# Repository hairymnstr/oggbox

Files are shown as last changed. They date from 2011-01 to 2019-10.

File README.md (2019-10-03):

OggBox
======

Author: nathan@nathandumont.com
License: 
* C code directly contained in this repository BSD-2-clause
* 3rd party libraries (FreeRTOS etc) see their own license terms
* schematic and CAD files CC0 1.0

The OggBox is an open hardware music player.  It supports OggVorbis and WAV files
using a dedicated codec chip from VLSI.  The source code for the main processor
(an ARM Cortex) is written in C and can be found under src/firmware.

Originally it was developed using the toolchain built with
<https://github.com/esden/summon-arm-toolchain> but can be built with newer
toolchains that provide arm-none-eabi-gcc and an appropriate newlib

    sudo apt install gcc-arm-none-eabi

will install a suitable toolchain on Ubuntu 18.04.

Flashing the device can be done via a suitable SWD probe and OpenOCD, or using
the FTDI header and <https://sourceforge.net/p/stm32flash/wiki/Home/>.  You may 
need to adjust the Makefile as the install target uses a specific device on my
computer so that it doesn't try and access any other FTDI devices attached to my PC.

The schematics have recently been ported to KiCAD v5.2 format and are under /sch
the libraries required are pulled in as local to the project as git submodules.

What documentation exists is linked from <http://oggbox.nathandumont.com>

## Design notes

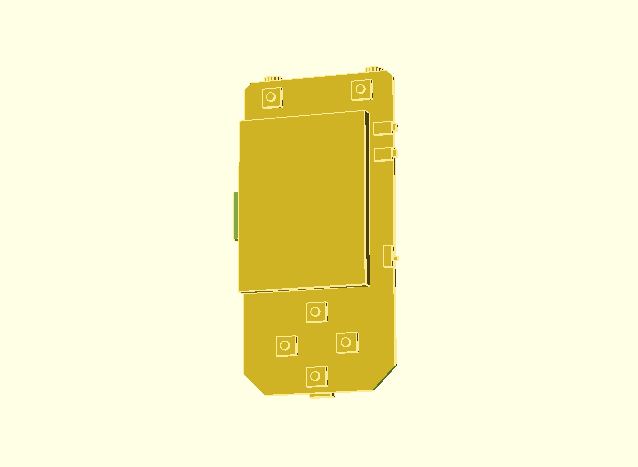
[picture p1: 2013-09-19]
cad/pcba_front.png

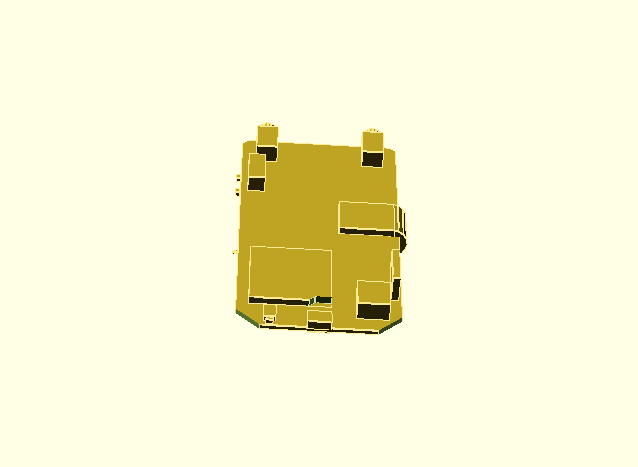
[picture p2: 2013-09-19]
cad/pcba_back.png

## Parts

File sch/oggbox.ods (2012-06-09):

Reference | Value | Footprint | Qty. | Farnell | Stock
B1 | LIPO | JUMPER | 1 |  | 1
C1, C2 | 18p | SM0805 | 2 | 1759194
C19, C22, C26, C30, C47, C48 | 4.7u | SM0805 | 6 | 1759420 | 90
C23 | 47u | SM1206 | 1 | 1658446
C24, C25 | 10p | SM0805 | 2 | 1759191
C28, C29 | 27p | SM0805 | 2 | 1759196
C3, C4, C43, C44 | 1u | SM0805 | 4 | 1759422
C37, C39, C40, C41 | 2.2u | SM0805 | 4 | 1759177 | 96
C5, C6, C18, C20, C21 | 0.01u | SM0805 | 5 | 1759247
C7, C8, C9, C10, C11, C12, C13, C14, C15, C16, C17, C27, C32, C33, C34, C35, C36, C42, C45, C46, C49, C50, C51, C52, C53, C54, C55 | 0.1u | SM0805 | 27 | 1759166 | 95
D1 | LED_RG | SOT23 | 1 | 1142614
IC1 | VS1053 | LQFP48 | 1 | --- | 1
IC2 | MCP73831T | SOT23-5 | 1 | 1332158 | 2
IC3 | SD_CARD | SD_CARD9186158 | 1 | 9186158
IC4 | MCP1802T-3002I-OT | SOT23-5 | 1 | 1578373
IC5 | STM32F103RBT | LQFP64 | 1 | 1447640
IC7 | TPS76318 | SOT23-5 | 1 | 8461341
IC8 | TPS76328 | SOT23-5 | 1 | 1755503
IC9 | MCP102 | SOT23 | 1 | 8752842
L1 | 470n | SM1206 | 1 | 1711870
P2 | USB | MICRO_USB_1568026 | 1 | 1568026
P5 | CONN_4 | BTHQ128064AVD1 | 1 | 9449388
P6 | CONN_28 | AMP_FPC_28_05MM | 1 | 1816385
P7 | FTDI | HEADER_6 | 1 |  | 1
P8 | JTAG | header_smd | 1 |  | 1
P9, P10 | LINE, PHONES | JACK_LUMBERG_1503_13_VP3 | 2 | 1368640
Q1, Q2 | BC817 | SOT23 | 2 | 1081223
Q3, Q4 | BSH121 | SOT23 | 2 | 1758072
R1, R4, R5, R6, R7, R8, R9, R10, R14, R23, R24, R25, R26, R32, R33, R34, R37, R38, R40, R41, R43, R44, R46, R48, R49, R50, R51, R52 | 10k | SM0805 | 28 | 9333720
R12, R42 | 1M | SM0805 | 2 | 9333746 | 49
R13 | 47k | SM0805 | 1 | 9334599
R15 | 36k | SM0805 | 1 | 9334440
R16 | 1.5k | SM0805 | 1 | 9333924
R17, R18 | 470 | SM0805 | 2 | 9334572
R19 | 15k | SM0805 | 1 | 9333932
R2, R11 | 120 | SM0805 | 2 | 9333819
R20, R21 | 22 | SM0805 | 2 | 9334122
R22, R57 | 22k | SM0805 | 2 | 9334157
R27, R28 | 100k | SM0805 | 2 | 9333738
R29 | 10 | SM0805 | 1
R3, R56 | 1k | SM0805 | 2 | 9333711
R30, R31 | 20 | SM0805 | 2
R35 | 3k3 | SM0805 | 1 | 9334360
R36 | 12k | SM0805 | 1 | 9333835
R39 | 0 | SM0805 | 1
R53, R54 | 27 | SM0805 | 2 | 9334246 | 48
SW1, SW2, SW3 | VOL_UP, VOL_DN, RESET | SW_B3U-3000P-B | 3 | 1333656
SW4, SW5, SW7, SW8, SW9, SW10 | MENU, SET, DOWN, LEFT, RIGHT, UP | SW_EVQQ2P03W | 6 | 9962859
SW11 | HOLD | PCM12SMTR | 1 | 9575146
X1 | 12.288MHz | HC49SM | 1 | 1611787
X2 | 32768Hz | CFS206 | 1 | 1457085 | 1
X3 | 8MHz | HC49SM | 1 | 1842346

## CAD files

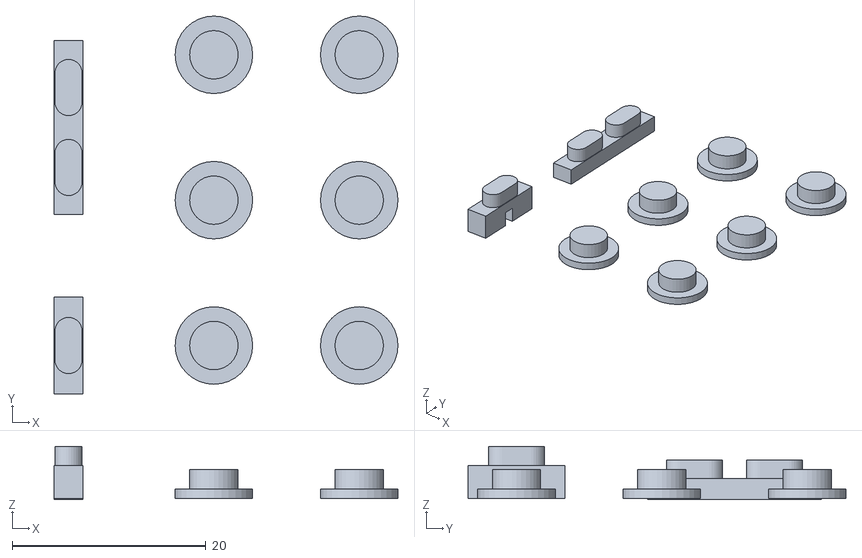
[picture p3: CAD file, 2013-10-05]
cad/oggbox_buttons.stl
35.5 x 39.0 x 5.50

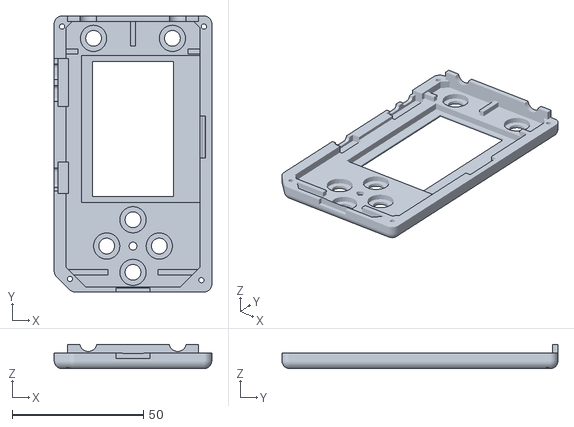
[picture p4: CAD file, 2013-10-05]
cad/oggbox_front.stl
60.0 x 105.0 x 9.24

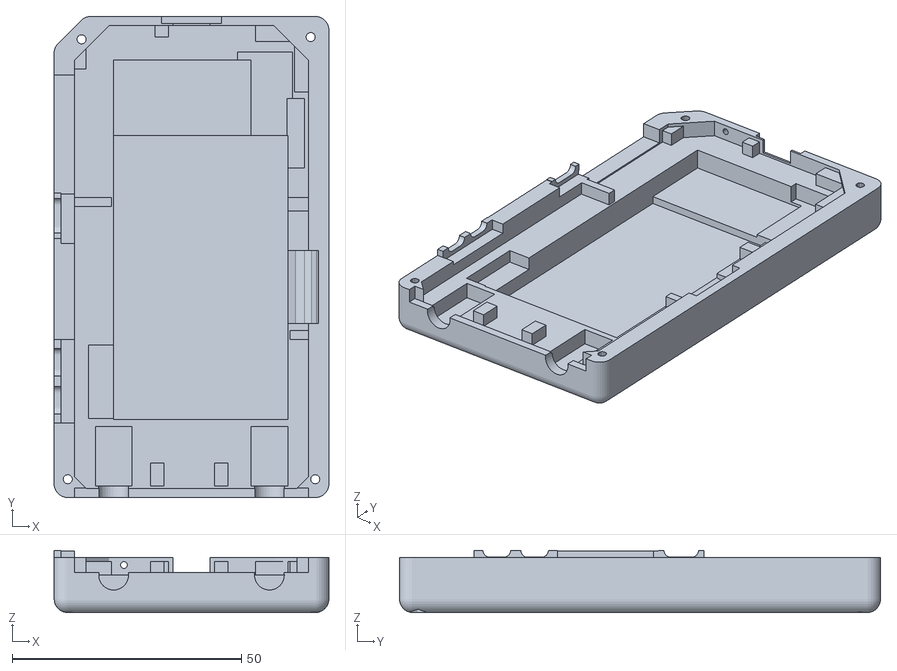
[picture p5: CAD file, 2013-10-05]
cad/oggbox_back.stl
60.0 x 105.0 x 13.6

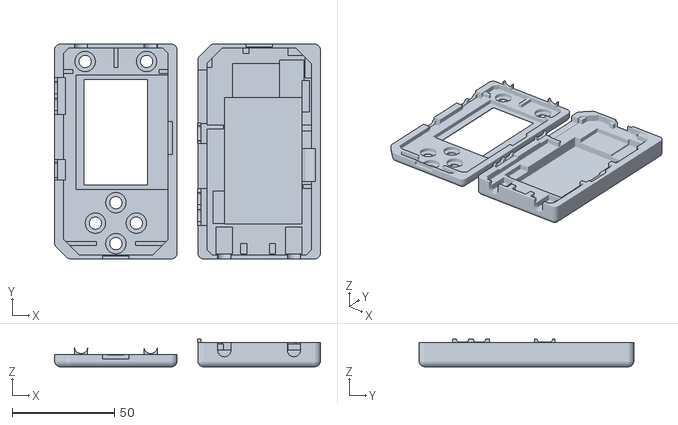
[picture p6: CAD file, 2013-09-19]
cad/oggbox.stl
130.0 x 105.0 x 13.6

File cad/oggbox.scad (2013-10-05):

module screen() {
	union() {
		difference() {
			translate([1.3,1,2.95]) cylinder(r1=5,r2=5,h=14.7,$fn=16, center=true);
			translate([-5,4.405,-5]) cube([10,5,20]);
		}
		translate([-1,0,-27.3]) cube([42.2,4.405,54.6]);
		translate([9.25,-2.75,2.95]) cube([17.5,2.5,14.7], center=true);
	}
}

module switch() {
	union() {
		translate([0,0.9,0]) cube([6.6,1.8,6.2],center=true);
		translate([0,2.3,0]) rotate([90,0,0]) cylinder(r1=1.5, r2=1.5, h=1, $fn=16, center=true);
	}
}

module side_switch() {
	union() {
		translate([0,0.9,0]) cube([4,1.8,6],center=true);
		translate([0,0.9,3.75]) cube([2.4,1.6,1.5],center=true);
	}
}

module hold_switch() {
	union() {
		translate([-3.35,0,-1.4]) cube([6.7,1.95,2.8]);
		translate([-1.5,.575,1.4]) cube([1.35,.8,1.9]);
	}
}

module sdcard_holder() {
	difference() {
		translate([0,0,-13.25]) cube([25,2.5,26.5]);
		translate([-0.1,-0.1,-13.35]) cube([5.1,3,2.1]);
		translate([5,1.25,-13.25]) rotate([0,45,0]) cube([2.828,3,2.828],center=true);
	}
}

module jack_socket() {
	union() {
		translate([-3.5,0,2.5]) cube([7,6,12]);
		translate([0,3,1.5]) rotate() cylinder(r1=3, r2=3, h=2.5, $fn=16, center=true);
	}
}

module usb_socket() {
	translate([-3.75,0,0]) cube([7.5,3,5.5]);
}

module programming_header() {
	translate([-7.62,0,-1.27]) cube([15.24,8.5,2.54]);
}

module cortex_debug() {
	translate([0,2.7,0]) cube([13.65,5.4,5.6], center=true);
}

module battery_connector() {
	translate([-5,0,-9.5]) cube([10,6,11.5]);
}

module pcba() {
	union() {
		// PCB
		difference() {
			cube([50.0,1.6,100.0], center = true);
			translate([25,0,50]) rotate([0,45,0]) cube([3.5355,3.5355,3.5355], center=true);
			translate([-25,0,50]) rotate([0,45,0]) cube([3.5355,3.5355,3.5355], center=true);
			translate([25,0,-50]) rotate([0,45,0]) cube([10.6066,10.6066,10.6066], center=true);
			translate([-25,0,-50]) rotate([0,45,0]) cube([10.6066,10.6066,10.6066], center=true);
		}
		// screen
		translate([24,0.8,9.5]) rotate([0,180,0]) screen();

		// buttons
		translate([15,0.8,44]) switch();
		translate([-15,0.8,44]) switch();
		translate([0,0.8,-25]) switch();
		translate([0,0.8,-45]) switch();
		translate([10,0.8,-35]) switch();
		translate([-10,0.8,-35]) switch();

		// volume switches
		translate([-22,0.8,31.25]) rotate([0,270,0]) side_switch();
		translate([-22,0.8,23]) rotate([0,270,0]) side_switch();
		// reset switch
		translate([-14.75,-0.8,-45]) rotate([0,180,180]) side_switch();

		// hold switch
		translate([-23.5,0.8,-9]) rotate([0,270,0]) hold_switch();

		// sd card holder
		translate([3.75,-0.8,-26.5]) rotate([180,180,0]) sdcard_holder();

		// jack sockets
		translate([-17,-0.8,52.25]) rotate([0,180,180]) jack_socket();
		translate([17,-0.8,52.25]) rotate([0,180,180]) jack_socket();

		// USB socket
		translate([0,-0.8,-51]) rotate([180,180,0]) usb_socket();

		// programming header
		translate([22.75,-0.8,-27]) rotate([180,90,0]) programming_header();

		// Cortex-debug connector
		translate([-20,-0.8,27.25]) rotate([180,90,0]) cortex_debug();

		// battery connector
		translate([16,-0.8,-42.75]) rotate([180,0,0]) battery_connector();

	}
}

module sdcard() {
	difference() {
		cube([24,2.1,32], center=true);
		translate([-12,0,-16]) rotate([0,45,0]) cube([5.65,5.65,5.65], center=true);
	}
}

module button_hole() {
	union() {
		translate([0,4.5,0]) rotate([90,0,0]) cylinder(r1=3,r2=3,h=4,$fn=32,center=true);
		rotate([270,0,0]) cylinder(r1=5,r2=5,h=9.6,$fn=32,center=true);
	}
}

module side_switch_hole() {
	union() {
		translate([2.5,0,0]) cube([4,5,10],center=true);
		cube([3,3,3],center=true);
		translate([0,0,-1.5]) rotate([0,90,0]) cylinder(r1=1.5,r2=1.5,h=3,$fn=32,center=true);
		translate([0,0,1.5]) rotate([0,90,0]) cylinder(r1=1.5,r2=1.5,h=3,$fn=32,center=true);
	}
}

module hold_switch_hole() {
	union() {
		translate([2.5,0,0]) cube([4,5,12],center=true);
		cube([3,3,4.5],center=true);
		translate([0,0,-2.25]) rotate([0,90,0]) cylinder(r1=1.5,r2=1.5,h=3,$fn=32,center=true);
		translate([0,0,2.25]) rotate([0,90,0]) cylinder(r1=1.5,r2=1.5,h=3,$fn=32,center=true);
	}
}

module upper_case() {
	union() {
	difference() {
		union() {
		difference() {
			translate([-27,-3,-49.5]) {
				minkowski() {
					difference() {
						cube([54,6,99]);
						rotate([0,45,0]) cube([sqrt(50),20,sqrt(50)],center=true);
					}
					sphere(r=3,$fn=32);
				}
			}
			translate([0,-3,0]) cube([62,6,106],center=true);
		}
		translate([0,0,51.5]) cube([50,6.5,2],center=true);
		
		}

		// status LED hole
		translate([0,5,-35]) rotate([90,0,0]) cylinder(r1=1.5,r2=1.5,h=5,$fn=32,center=true);

		// button holes
		translate([15,0,44]) button_hole();
		translate([-15,0,44]) button_hole();
		translate([0,0,-25]) button_hole();
		translate([0,0,-45]) button_hole();
		translate([10,0,-35]) button_hole();
		translate([-10,0,-35]) button_hole();

		// volume switch holes
		translate([-29,1.6,31.25]) side_switch_hole();
		translate([-29,1.6,23]) side_switch_hole();

		// hold switch hole
		translate([-29,1.6,-9]) hold_switch_hole();
		translate([-29,0,11.125]) cube([7.1,3,50.25],center=true);
		
		translate([-17,-0.8,52.5]) rotate([0,0,180]) jack_hole();
		translate([17,-0.8,52.5]) rotate([0,0,180]) jack_hole();

		// pcb hole
		difference() {
			cube([51,5.6,101],center=true);
			translate([25.5,0,50.5]) rotate([0,45,0]) cube([3.5355,10,3.5355],center=true);
			translate([-25.5,0,50.5]) rotate([0,45,0]) cube([3.5355,10,3.5355],center=true);
			translate([-25.5,0,-50.5]) rotate([0,45,0]) cube([10.6066,10,10.6066],center=true);
			translate([25.5,0,-50.5]) rotate([0,45,0]) cube([10.6066,10,10.6066],center=true);
		}

		// screen recess
		translate([24,0.8,9.5]) translate([-43.5,-2,-28]) cube([45,6.5,56]);
		
		// screen hole
		translate([-15.5,4,-25.75+9.5]) cube([31,5,51.5]);

		// screen ribbon clearance
		translate([24,0.8,9.5]) translate([-1.3,-1,-2.95]) cylinder(r1=5,r2=5,h=16,$fn=16,center=true);

		// usb socket
		translate([0,0,-51]) usb_socket_hole();

		// screw holes
		translate([26,0,-48]) rotate([90,0,0]) cylinder(r1=1, r2=1, h=30, $fn=16, center=true);
		translate([27,0,48.5]) rotate([90,0,0]) cylinder(r1=1, r2=1, h=30, $fn=16, center=true);
		translate([-27,0,48.5]) rotate([90,0,0]) cylinder(r1=1, r2=1, h=30, $fn=16, center=true);
		translate([-24,0,-47.5]) rotate([90,0,0]) cylinder(r1=1, r2=1, h=30, $fn=16, center=true);
		translate([26,6,-48]) rotate([90,0,0]) cylinder(r1=1.5,r2=1.5,h=3,$fn=32);
		translate([27,6,48.5]) rotate([90,0,0]) cylinder(r1=1.5,r2=1.5,h=3,$fn=32);
		translate([-27,6,48.5]) rotate([90,0,0]) cylinder(r1=1.5,r2=1.5,h=3,$fn=32);
		translate([-24,6,-47.5]) rotate([90,0,0]) cylinder(r1=1.5,r2=1.5,h=3,$fn=32);
	}
	// PCB support bars
	translate([-1,0.8,41]) cube([2,3,10]);
	translate([-24.5,0.8,-46]) cube([15,3,2]);
	translate([9.5,0.8,-46]) cube([15,3,2]);
	translate([21,0.8,38]) cube([5,3,2]);
	translate([-26,0.8,38]) cube([5,3,2]);
	}

}

module jack_hole() {
	union() {
		translate([0,3.25,-9]) cube([8,7,13],center=true);
		translate([0,3,-2.6]) rotate() cylinder(r1=3.25,r2=3.25,h=4,$fn=32);
	}
}

module usb_socket_hole() {
	union() {
		translate([-4,-3.3,-1]) cube([8,3.5,5]);
		translate([-6.5,-5.8,-5]) cube([13,8,5]);
	}
}

module lower_case() {
union() {
	difference() {
	union() {
		translate([-29.25,0.8,31.25]) cube([1.5,1.6,10],center=true);
		translate([-29.25,0.8,23]) cube([1.5,1.6,10],center=true);
		translate([-29.25,0.8,-9]) cube([1.5,1.6,10],center=true);
		translate([-27.75,0,11.125]) cube([4.5,3,50],center=true);
		difference() {
			translate([-27,-9,-49.5]) {
				minkowski() {
					difference() {
						cube([54,12,99]);
						rotate([0,45,0]) cube([sqrt(50),30,sqrt(50)],center=true);
					}
					sphere(r=3,$fn=32);
				}
			}
			translate([0,3,0]) cube([62,6,106],center=true);
		}
		}

		// volume switch holes
		translate([-29,1.6,31.25]) side_switch_hole();
		translate([-29,1.6,23]) side_switch_hole();

		// hold switch hole
		translate([-29,1.6,-9]) hold_switch_hole();

		// pcb hole
		difference() {
			cube([51,7.6,101],center=true);
			translate([25.5,0,50.5]) rotate([0,45,0]) cube([3.5355,10,3.5355],center=true);
			translate([-25.5,0,50.5]) rotate([0,45,0]) cube([3.5355,10,3.5355],center=true);
			translate([-25.5,0,-50.5]) rotate([0,45,0]) cube([10.6066,10,10.6066],center=true);
			translate([25.5,0,-50.5]) rotate([0,45,0]) cube([10.6066,10,10.6066],center=true);
		}

		// screen ribbon clearance
		translate([24,0.8,9.5]) translate([-1.3,-1,-2.95]) cylinder(r1=5,r2=5,h=16,$fn=16,center=true);

		// jack holes
		translate([-17,-0.8,52.5]) rotate([0,0,180]) jack_hole();
		translate([17,-0.8,52.5]) rotate([0,0,180]) jack_hole();
//		translate([-17,0,52.5]) cube([6.5,6.5,6],center=true);
//		translate([17,0,52.5]) cube([6.5,6.5,6],center=true);
		translate([0,0,51.5]) cube([51,6.5,2.1],center=true);
		// cortex debug connector
		translate([-22.5,-6.8,19.25]) cube([7,6,16]);

		// programming header
		translate([22.75-(3.8/2),-9.3,-27 - (15.24/2)]) cube([3.8,8.5,15.24]);
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

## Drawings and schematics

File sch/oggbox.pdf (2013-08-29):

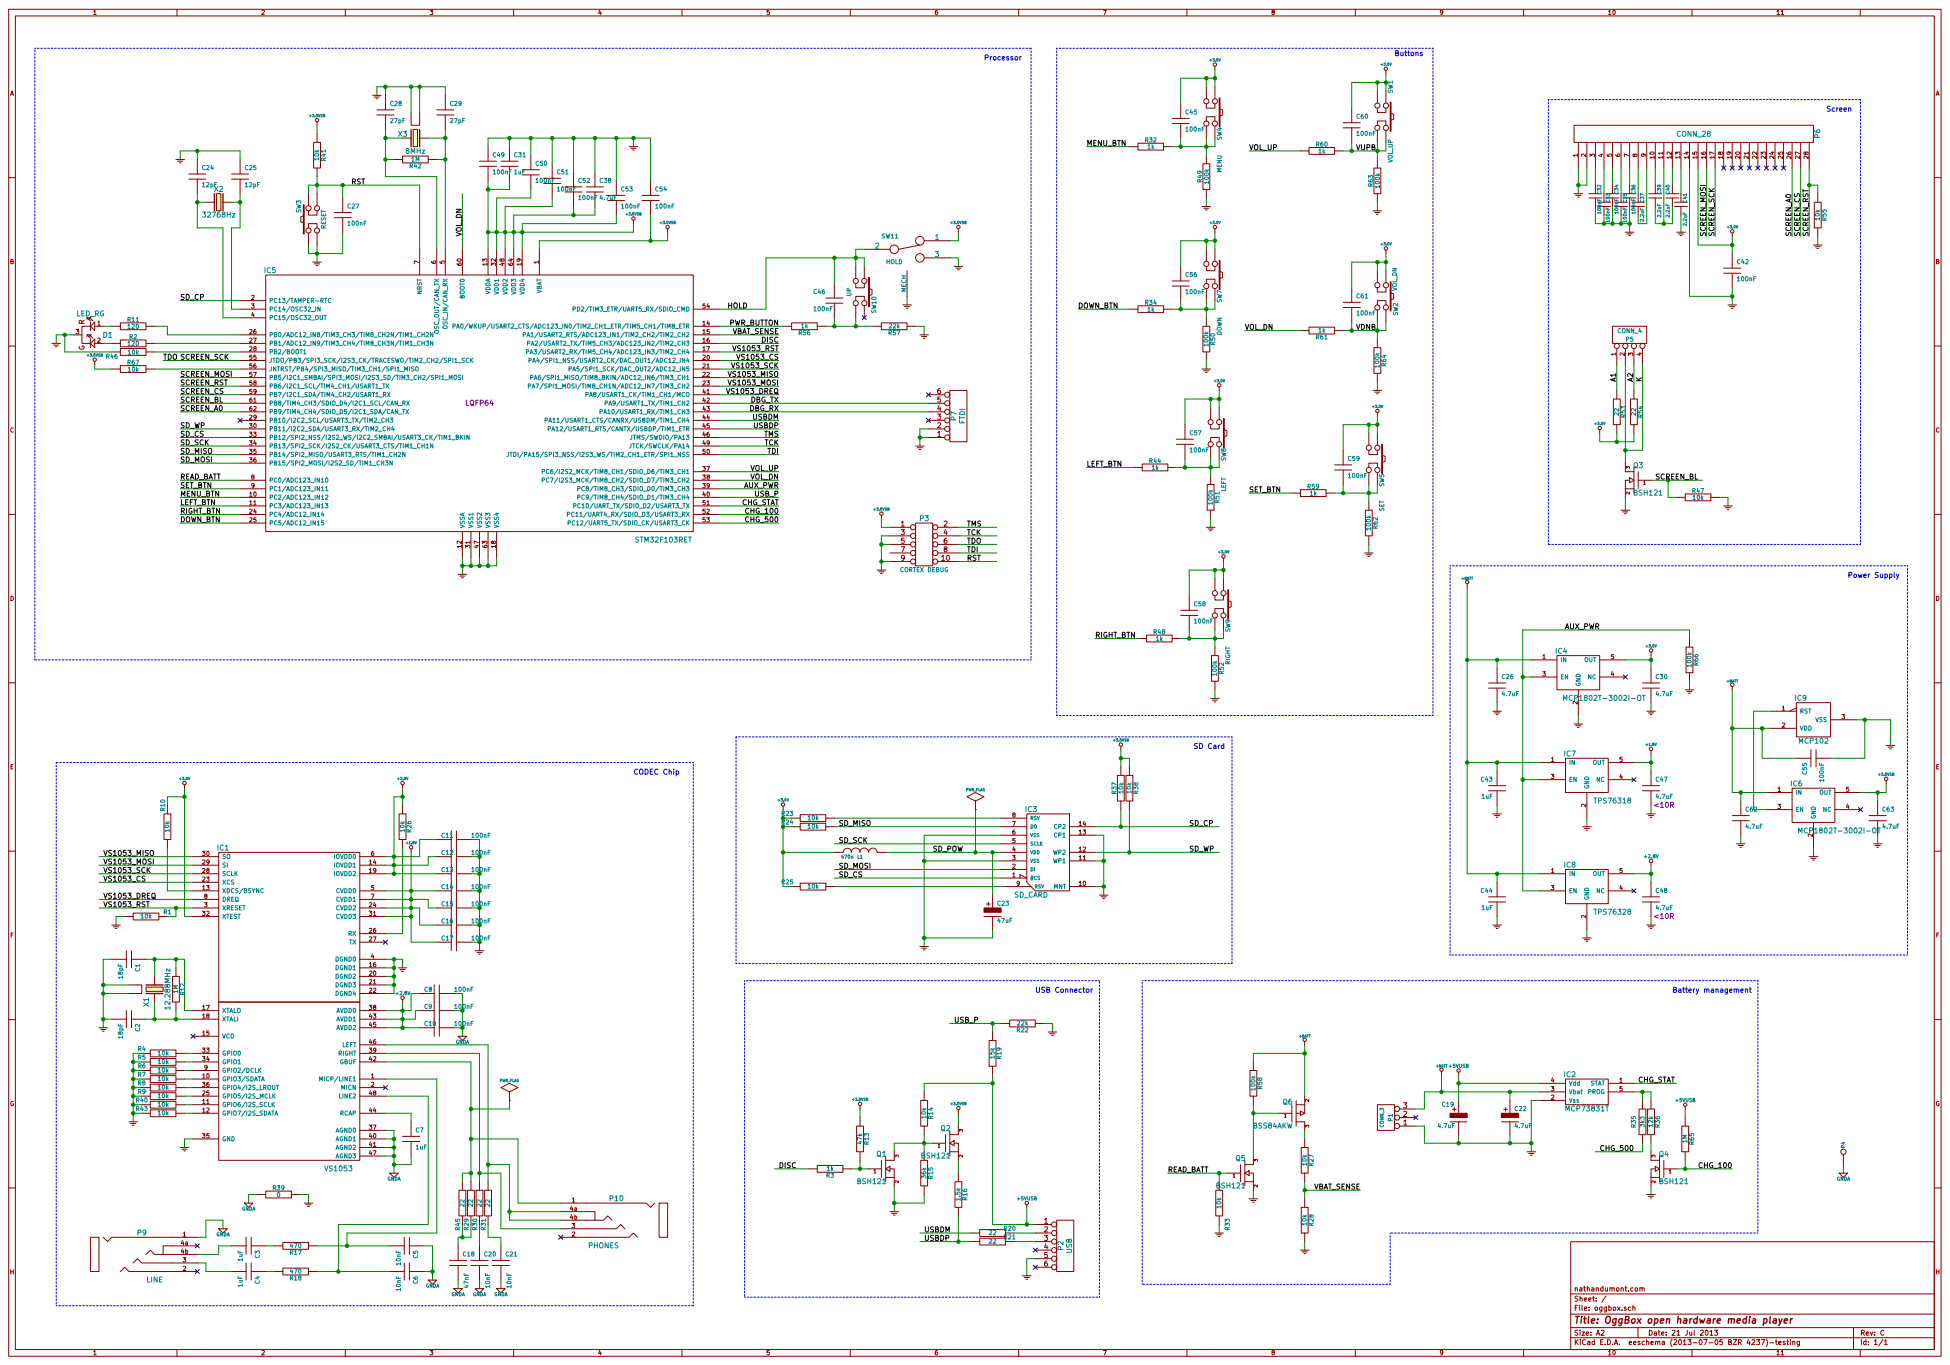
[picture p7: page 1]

File: oggbox.sch Sheet: / nathandumont.com

Id: 1/1 Title: OggBox open hardware media player

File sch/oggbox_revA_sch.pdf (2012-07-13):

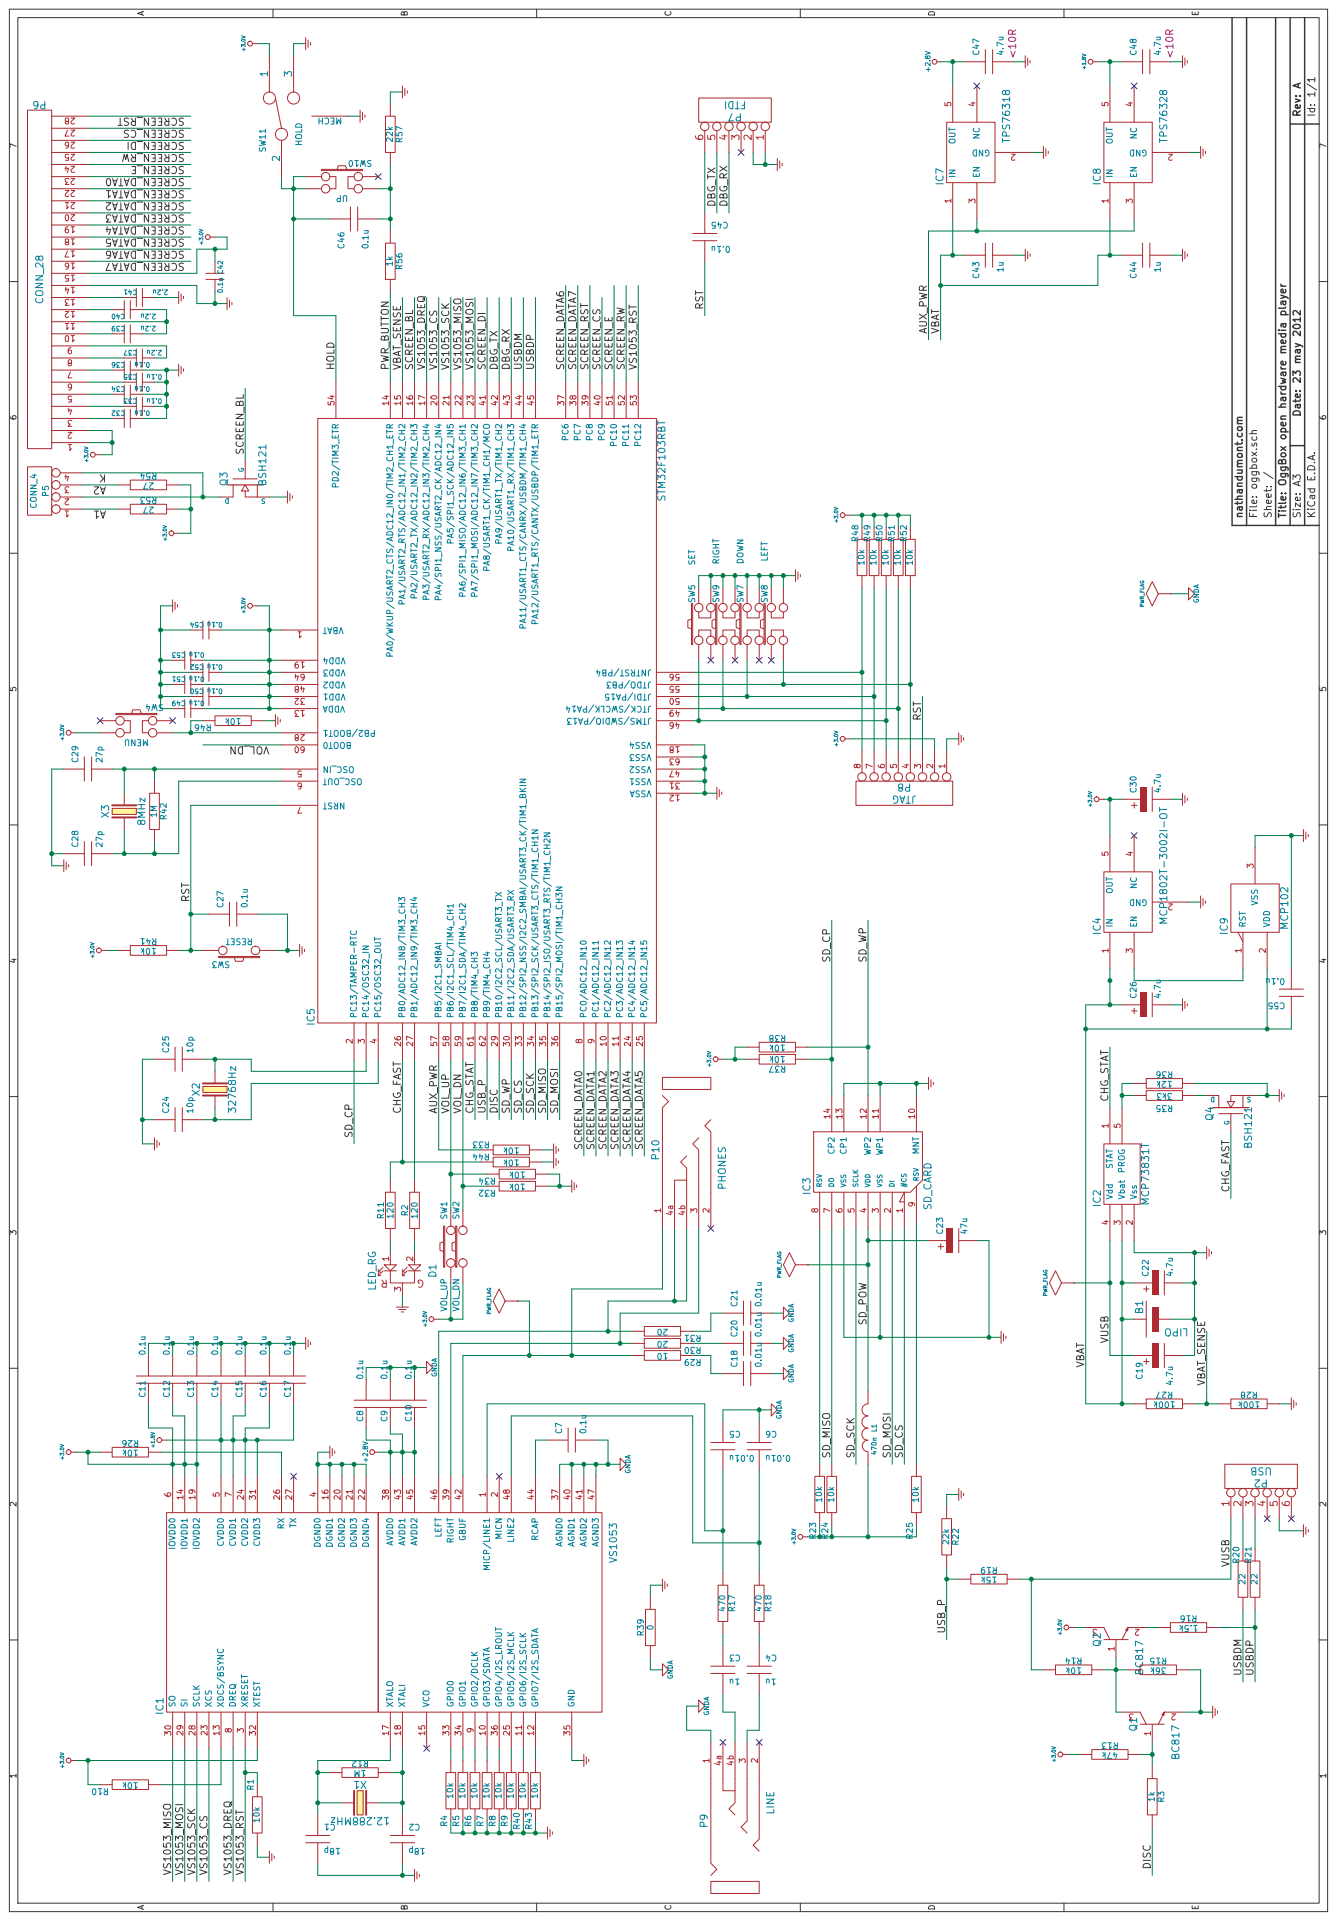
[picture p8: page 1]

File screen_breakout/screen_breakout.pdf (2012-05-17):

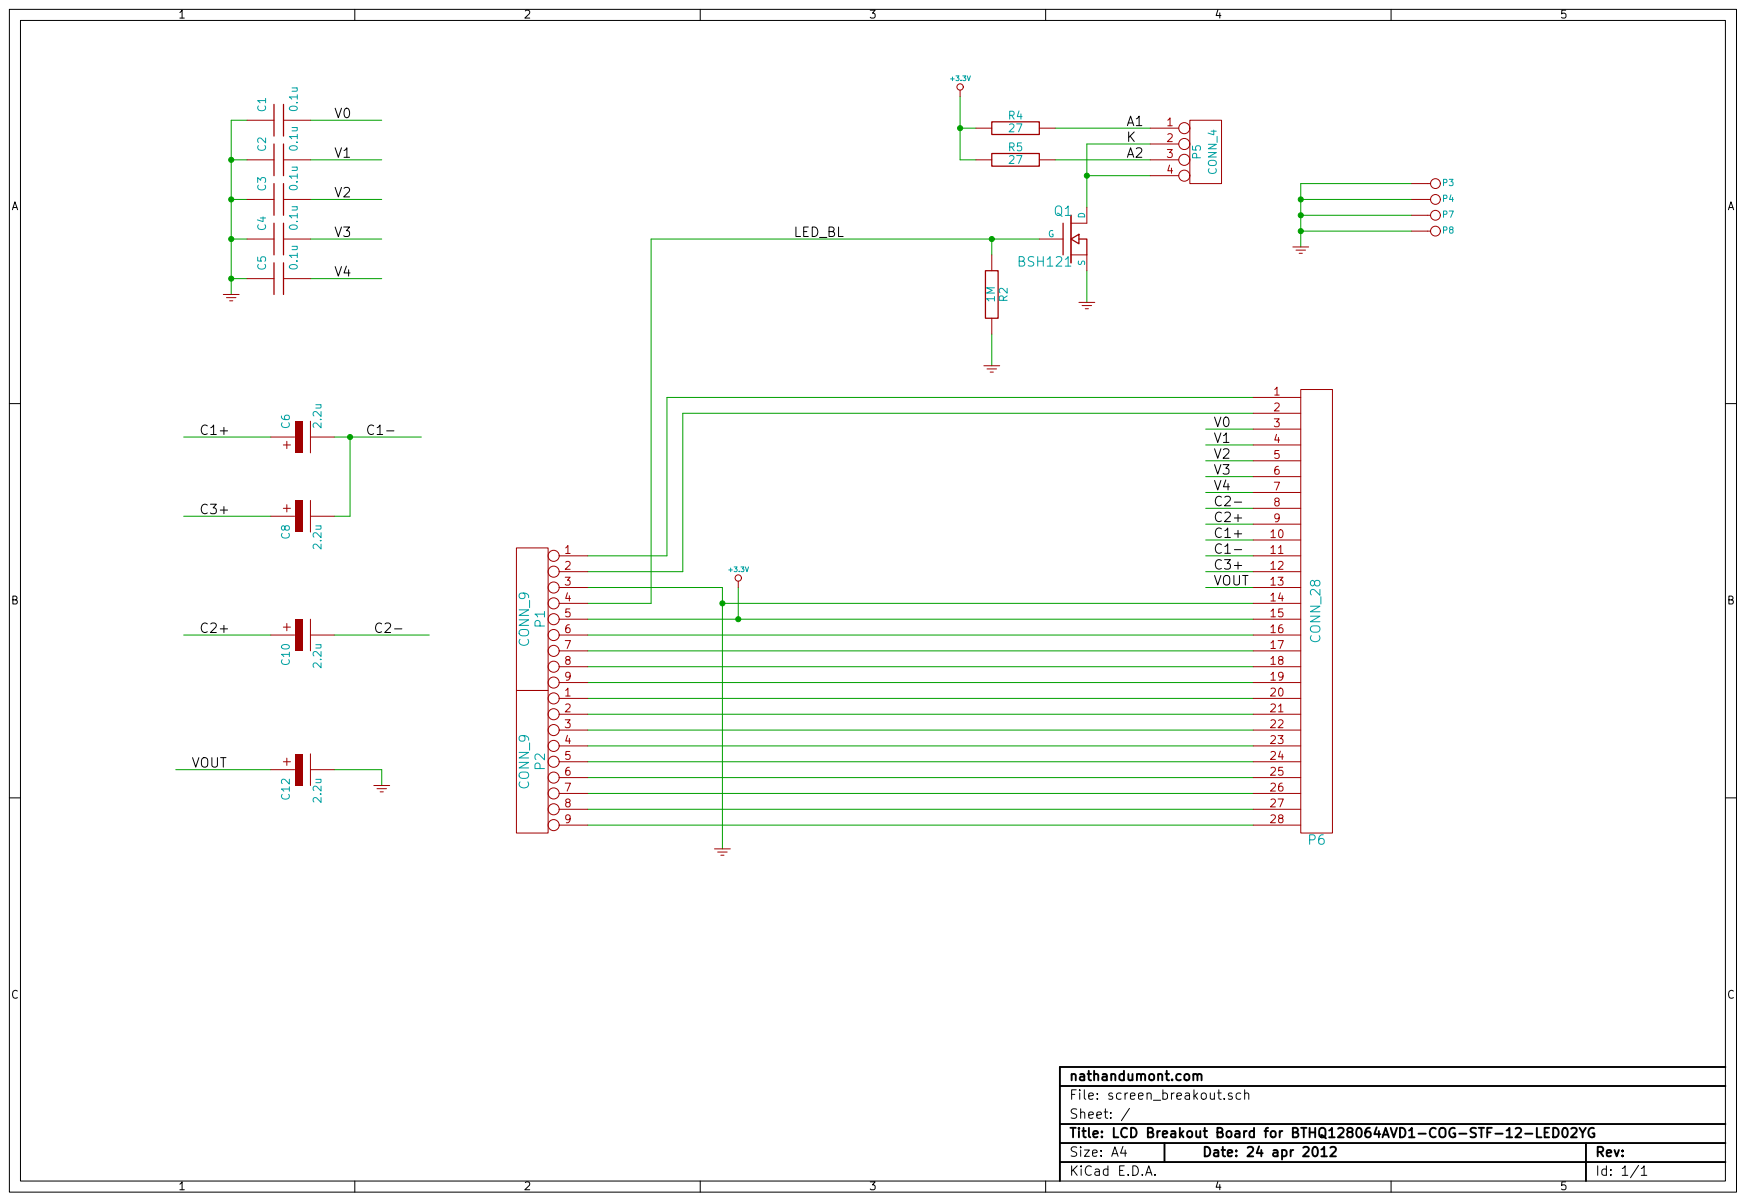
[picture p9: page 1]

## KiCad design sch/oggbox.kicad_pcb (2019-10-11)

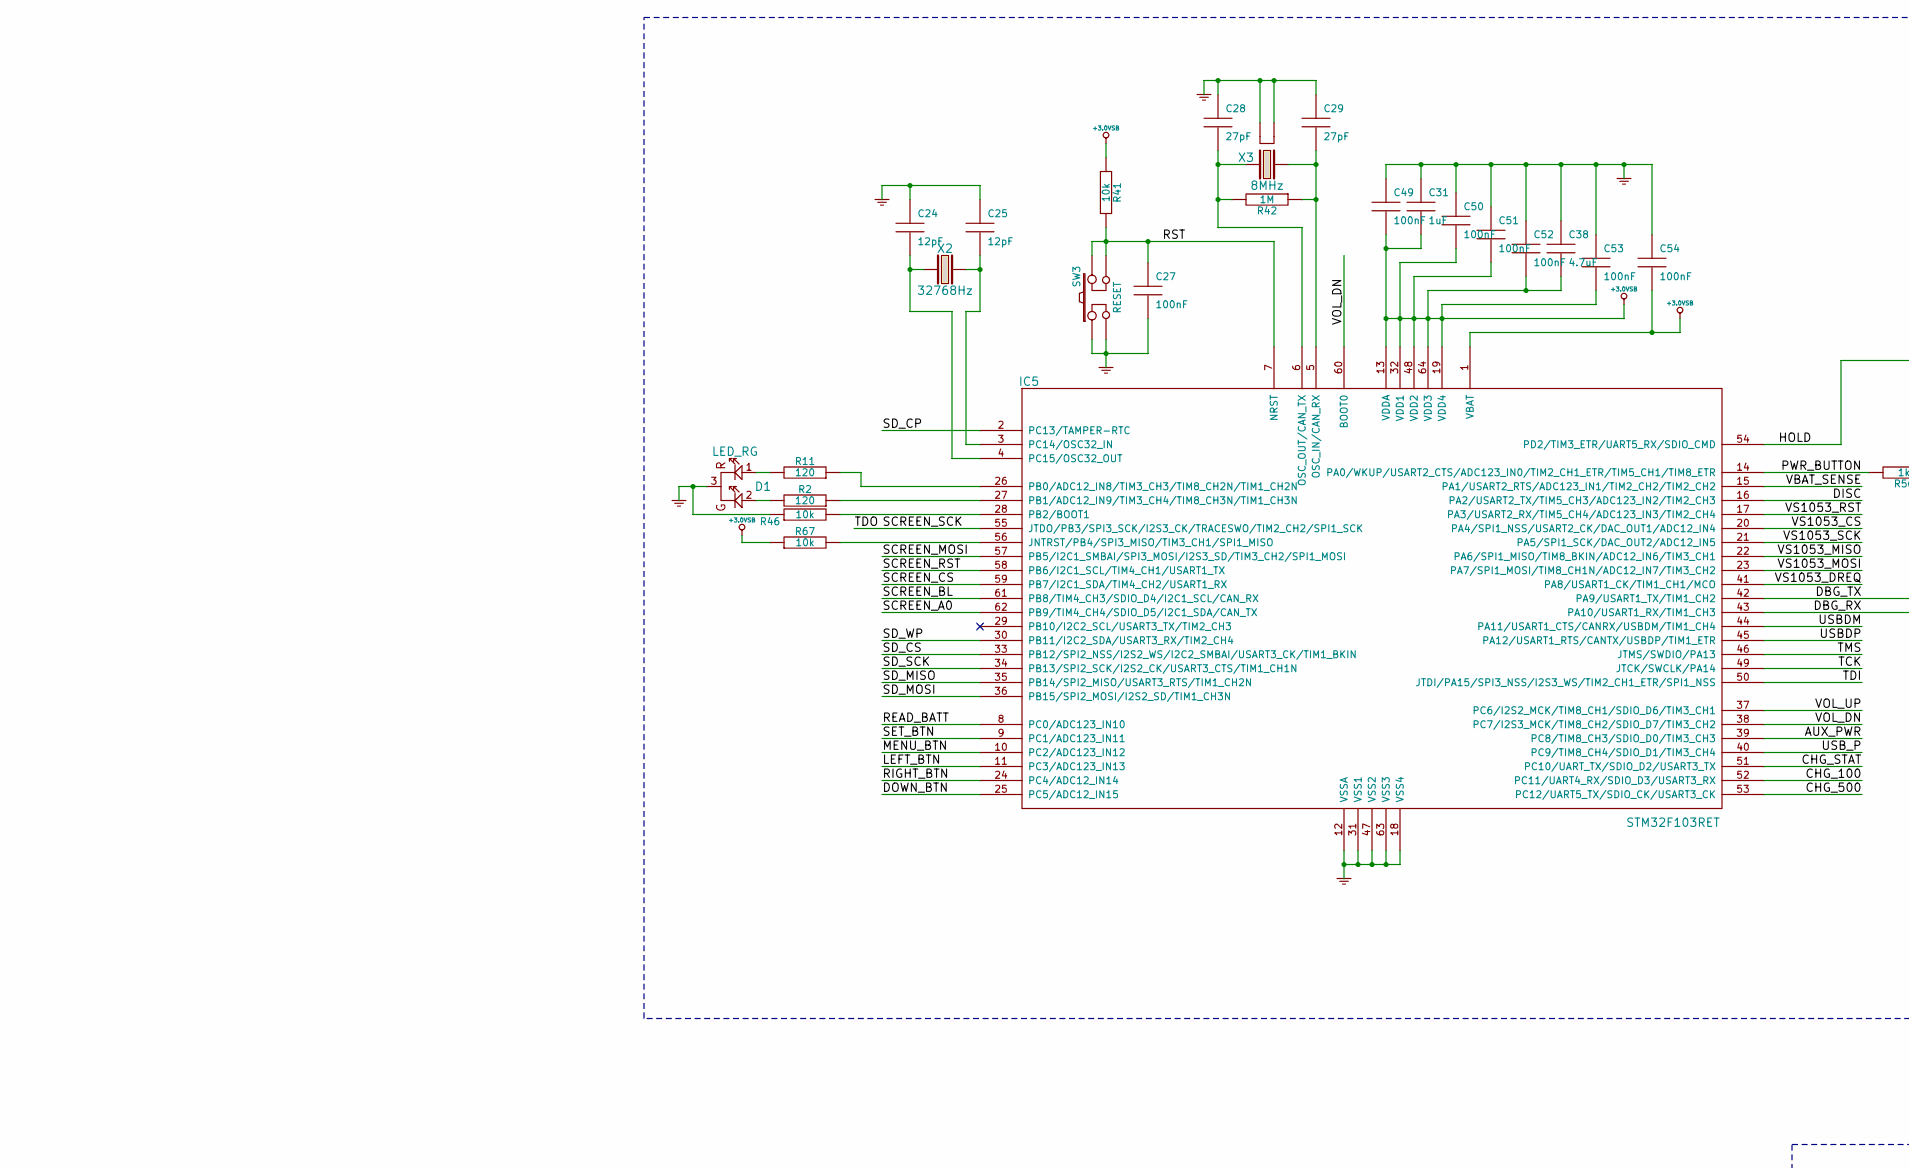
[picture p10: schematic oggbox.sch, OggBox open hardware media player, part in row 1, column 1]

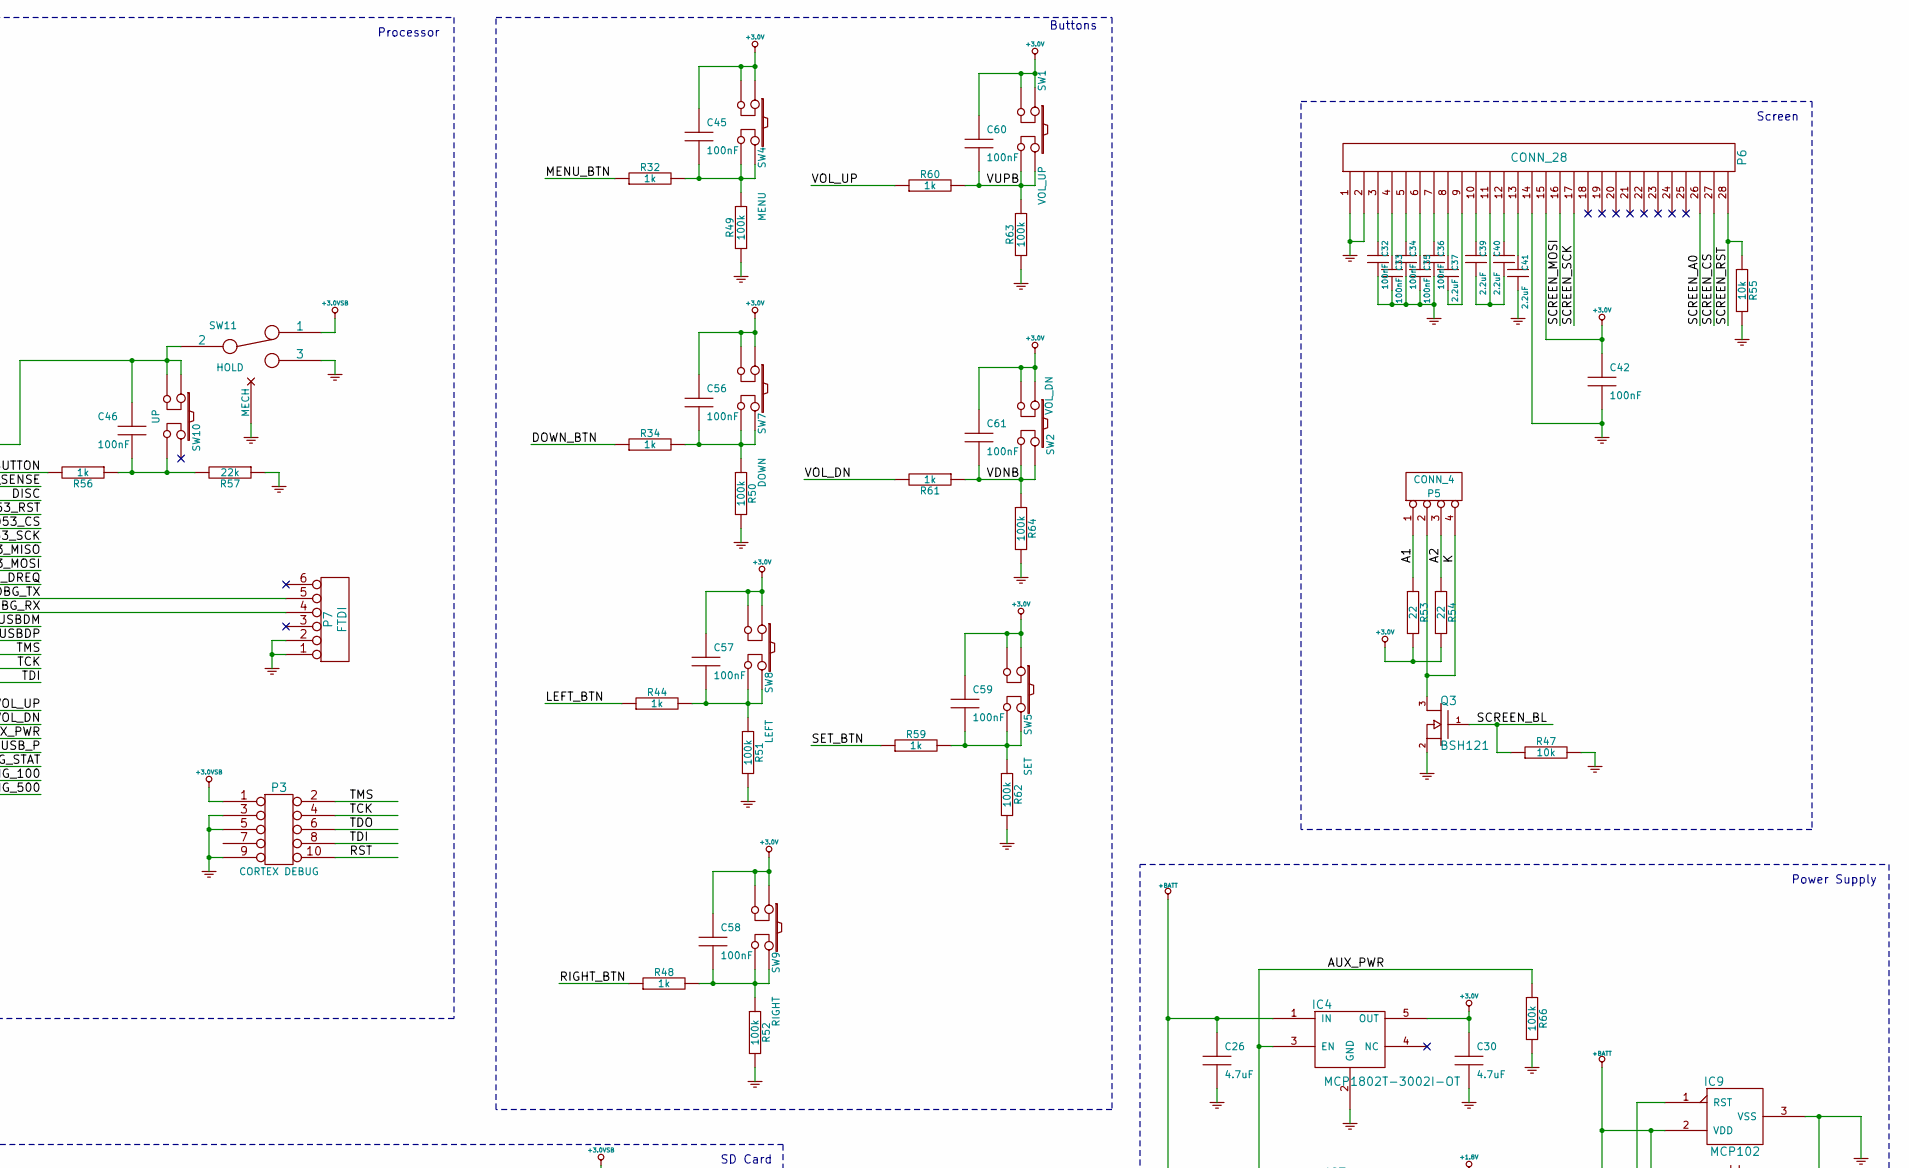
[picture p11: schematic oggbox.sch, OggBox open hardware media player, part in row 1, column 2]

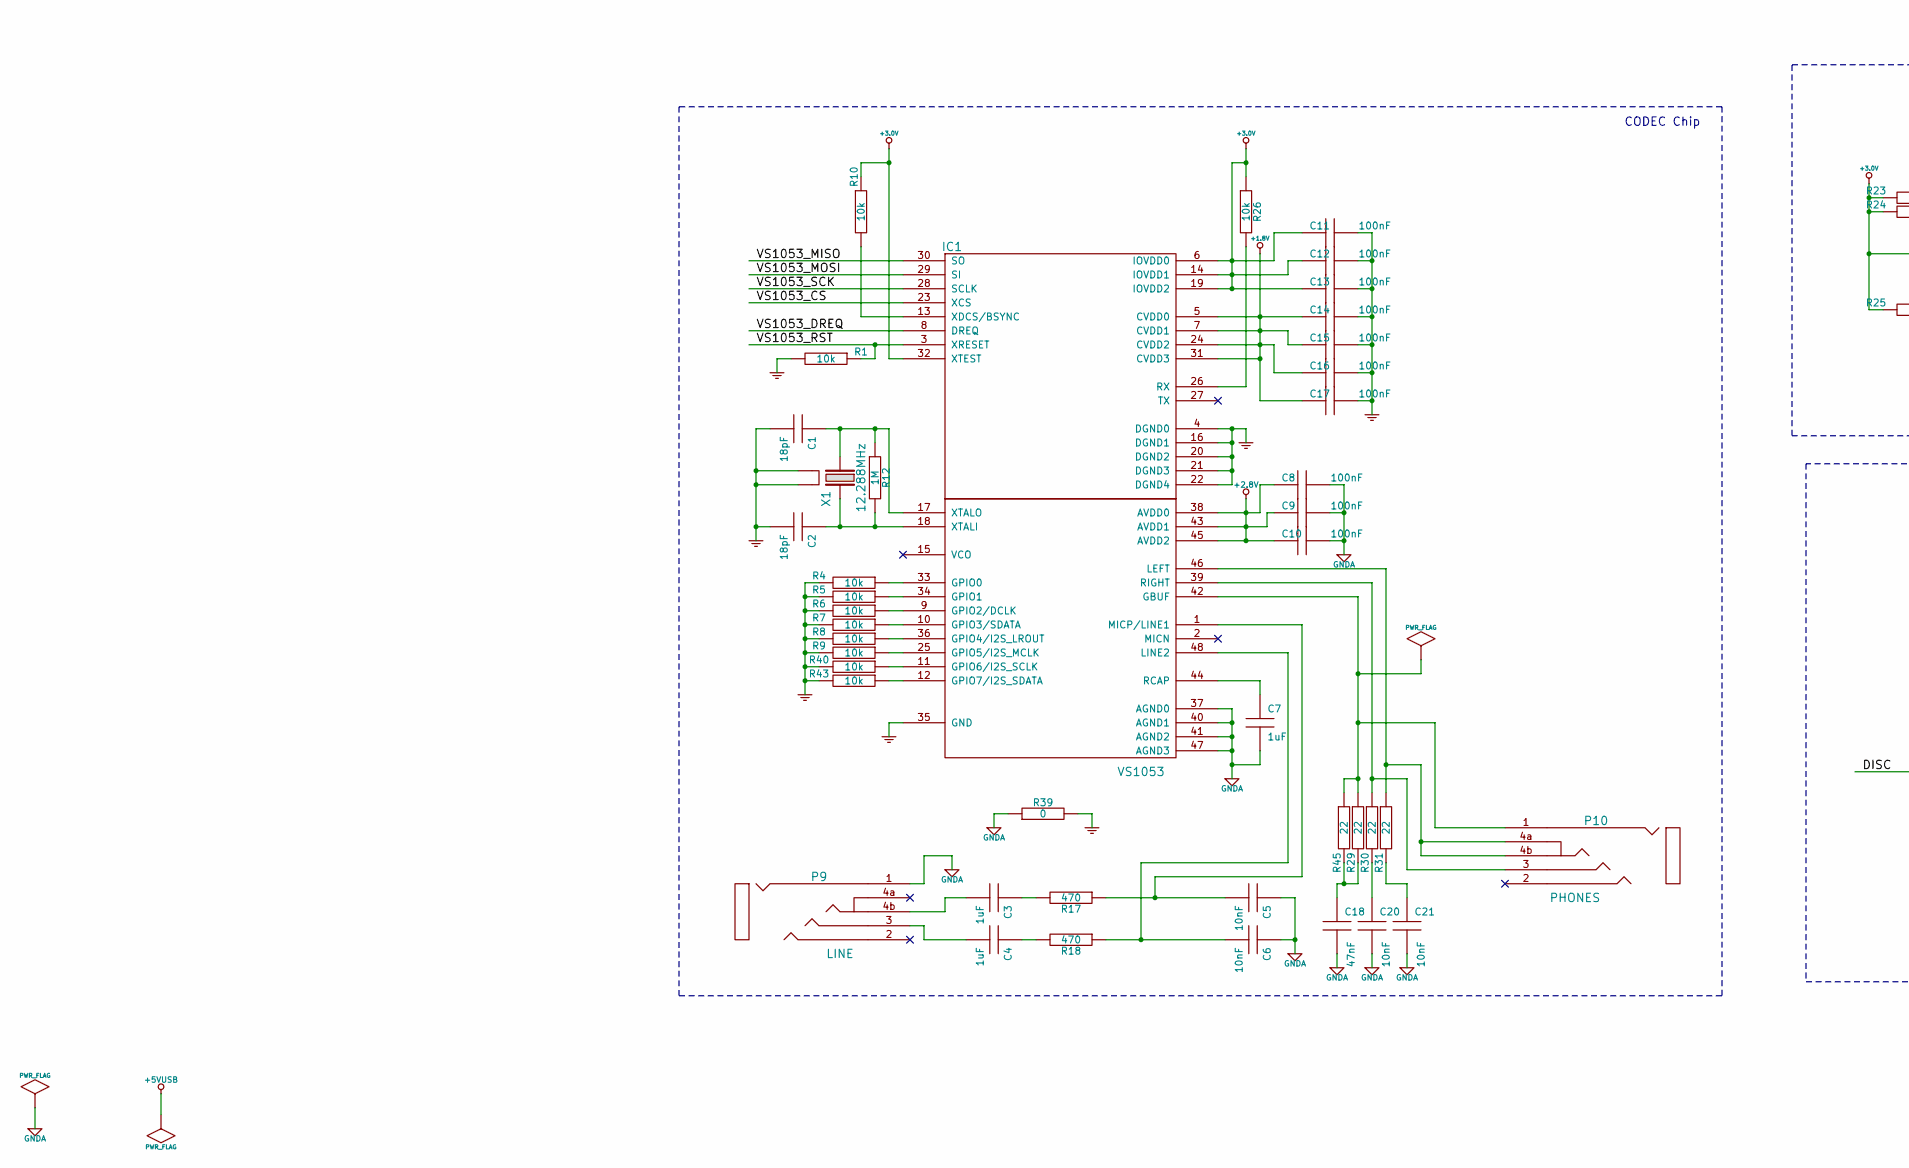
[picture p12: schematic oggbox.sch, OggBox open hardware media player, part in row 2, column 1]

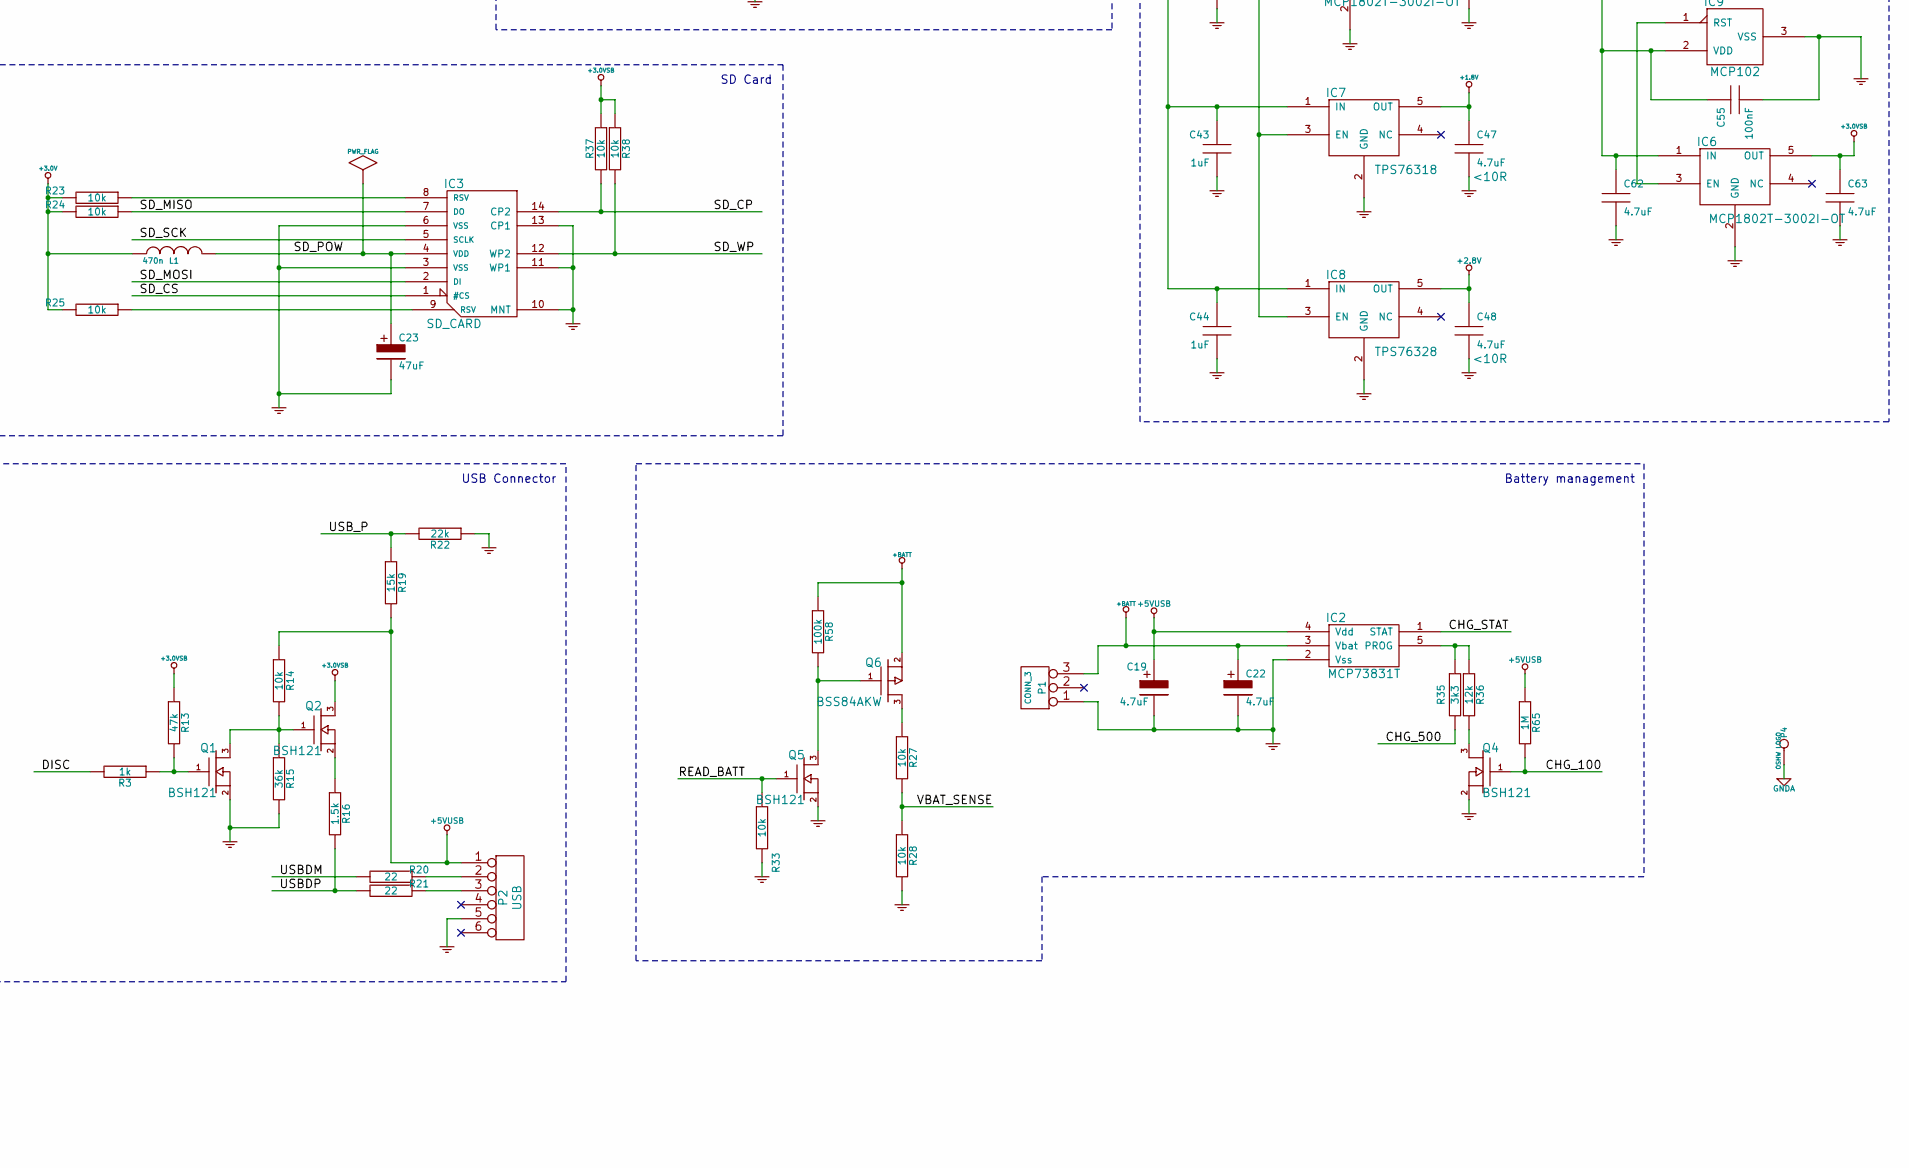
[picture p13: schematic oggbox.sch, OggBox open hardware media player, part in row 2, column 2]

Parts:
C1, C2: 18pF; SM0603
C3, C4, C7, C31, C43, C44: 1uF; SM0603
C5, C6, C20, C21: 10nF; SM0603
C8, C9, C10, C11, C12, C13, C14, C15, C16, C17, C27, C32, C33, C34, C35, C36, C42, C45, C49, C50, C51, C52, C53, C54, C55, C56, C57, C58, C59, C60, C61: 100nF; SM0603
C18: 47nF; SM0603
C19, C22, C26, C30, C38, C47, C48, C62, C63: 4.7uF; SM0805
C23: 47uF; SM1206
C24, C25: 12pF; SM0603; Tolerance 20%; Voltage 50V
C28, C29: 27pF; SM0603
C37, C39, C40, C41: 2.2uF; SM0805
C46: 100nF; SM0603; Tolerance 20%; Voltage 50V
D1: LED_RG; SOT23
IC1: VS1053; LQFP48
IC2: MCP73831T; SOT23-5
IC3: SD_CARD; SD_UNIVERSAL
IC4, IC6: MCP1802T-3002I-OT; SOT23-5
IC5: STM32F103RET; LQFP64
IC7: TPS76318; SOT23-5
IC8: TPS76328; SOT23-5
IC9: MCP102; SOT23
L1: 470n; SM1206
P1: CONN_3; JST_S3B_XHA
P2: USB; MICRO_USB_1568026
P3: CORTEX DEBUG; SAMTEC_SHF-SM_5x2
P4: OSHW LOGO; OSHW_COPPER_10MM
P5: CONN_4; BTHQ128064AVD1
P6: CONN_28; AMP_FPC_28_05MM
P7: FTDI; HEADER_6
P9: LINE; JACK_LUMBERG_1503_13_VP3
P10: PHONES; JACK_LUMBERG_1503_13_VP3
Q1, Q2, Q3, Q4, Q5: BSH121; SOT323
Q6: BSS84AKW; SOT323
R1, R4, R5, R6, R7, R8, R9, R10, R14, R23, R24, R25, R26, R27, R28, R33, R37, R38, R40, R43, R47, R55: 10k; SM0603
R2, R11: 120; SM0603; Tolerance 5%
R3, R32, R34, R44, R48, R59, R60, R61: 1k; SM0603
R12, R42, R65: 1M; SM0603
R13: 47k; SM0603
R15: 36k; SM0603
R16: 1.5k; SM0603
R17, R18: 470; SM0603
R19: 15k; SM0603
R20, R21, R29, R30, R31, R45, R53, R54: 22; SM0603
R22: 22k; SM0603
R35: 3k3; SM0603
R36: 12k; SM0603
R39: 0; SM0603
R41, R46, R67: 10k; SM0603; Tolerance 5%
R49, R50, R51, R52, R58, R62, R63, R64, R66: 100k; SM0603
R56: 1k; SM0603; Tolerance 5%
R57: 22k; SM0603; Tolerance 5%
SW1: VOL_UP; SW_SKQLLCE012
SW2: VOL_DN; SW_SKQLLCE012
SW3: RESET; SW_SKQLLCE012
SW4: MENU; SW_EVQQ2P03W
SW5: SET; SW_EVQQ2P03W
SW7: DOWN; SW_EVQQ2P03W
SW8: LEFT; SW_EVQQ2P03W
SW9: RIGHT; SW_EVQQ2P03W
SW10: UP; SW_EVQQ2P03W
SW11: HOLD; PCM12SMTR
X1: 12.288MHz; CRYSTAL-SMD-5-3_2
X2: 32768Hz; MC306
X3: 8MHz; CRYSTAL-SMD-5-3_2

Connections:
+1.8V: C14.2, C15.2, C16.2, C17.2, C47.1, IC1.5 (CVDD0), IC1.7 (CVDD1), IC1.24 (CVDD2), IC1.31 (CVDD3), IC7.5 (OUT)
+2.8V: C8.2, C9.2, C10.2, C48.1, IC1.38 (AVDD0), IC1.43 (AVDD1), IC1.45 (AVDD2), IC8.5 (OUT)
+3.0V: C11.2, C12.2, C13.2, C30.1, C42.1, C45.1, C56.1, C57.1, C58.1, C59.1, C60.1, C61.1, IC1.6 (IOVDD0), IC1.14 (IOVDD1), IC1.19 (IOVDD2), IC1.32 (XTEST), IC4.5 (OUT), L1.1, P6.15, R10.1, R23.2, R24.2, R25.2, R26.1, R53.2, R54.2, SW1.1, SW1.3, SW2.1, SW2.3, SW4.1, SW4.3, SW5.1, SW5.3, SW7.1, SW7.3, SW8.1, SW8.3, SW9.1, SW9.3
+3.0VSB: C31.2, C38.2, C49.2, C50.2, C51.2, C52.2, C53.2, C54.2, C63.1, IC5.1 (VBAT), IC5.13 (VDDA), IC5.19 (VDD4), IC5.32 (VDD1), IC5.48 (VDD2), IC5.64 (VDD3), IC6.5 (OUT), P3.1, Q2.3 (D), R13.1, R37.1, R38.1, R41.1, R67.1, SW11.1
+5VUSB: C19.1, IC2.4 (Vdd), P2.1, R14.1, R19.2, R65.1
+BATT: C22.1, C26.1, C43.1, C44.1, C55.1, C62.1, IC2.3 (Vbat), IC4.1 (IN), IC6.1 (IN), IC7.1 (IN), IC8.1 (IN), IC9.2 (VDD), P1.3, Q6.2 (S), R58.1
/A1: P5.1, R53.1
/A2: P5.3, R54.1
/AUX_PWR: IC4.3 (EN), IC5.39 (PC8/TIM8_CH3/SDIO_D0/TIM3_CH3), IC7.3 (EN), IC8.3 (EN), R66.1
/CHG_100: IC5.52 (PC11/UART4_RX/SDIO_D3/USART3_RX), Q4.1 (G), R65.2
/CHG_500: IC5.53 (PC12/UART5_TX/SDIO_CK/USART3_CK), R35.2
/CHG_STAT: IC2.1 (STAT), IC5.51 (PC10/UART_TX/SDIO_D2/USART3_TX)
/DBG_RX: IC5.43 (PA10/USART1_RX/TIM1_CH3), P7.4
/DBG_TX: IC5.42 (PA9/USART1_TX/TIM1_CH2), P7.5
/DISC: IC5.16 (PA2/USART2_TX/TIM5_CH3/ADC123_IN2/TIM2_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), R3.2
/DOWN_BTN: IC5.25 (PC5/ADC12_IN15), R34.1
/HOLD: C46.1, IC5.54 (PD2/TIM3_ETR/UART5_RX/SDIO_CMD), SW10.1, SW10.3, SW11.2
/K: P5.2, P5.4, Q3.3 (D)
/LEFT_BTN: IC5.11 (PC3/ADC123_IN13), R44.1
/MENU_BTN: IC5.10 (PC2/ADC123_IN12), R32.1
/PWR_BUTTON: IC5.14 (PA0/WKUP/USART2_CTS/ADC123_IN0/TIM2_CH1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), R56.2
/READ_BATT: IC5.8 (PC0/ADC123_IN10), Q5.1 (G), R33.1
/RIGHT_BTN: IC5.24 (PC4/ADC12_IN14), R48.1
/RST: C27.1, IC5.7 (NRST), P3.10, R41.2, SW3.2, SW3.4
/SCREEN_A0: IC5.62 (PB9/TIM4_CH4/SDIO_D5/I2C1_SDA/CAN_TX), P6.26
/SCREEN_BL: IC5.61 (PB8/TIM4_CH3/SDIO_D4/I2C1_SCL/CAN_RX), Q3.1 (G), R47.1
/SCREEN_CS: IC5.59 (PB7/I2C1_SDA/TIM4_CH2/USART1_RX), P6.27
/SCREEN_MOSI: IC5.57 (PB5/I2C1_SMBAI/SPI3_MOSI/I2S3_SD/TIM3_C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), P6.16
/SCREEN_RST: IC5.58 (PB6/I2C1_SCL/TIM4_CH1/USART1_TX), P6.28, R55.1
/SCREEN_SCK: IC5.55 (JTDO/PB3/SPI3_SCK/I2S3_CK/TRACESWO/TIM2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), P3.6, P6.17
/SD_CP: IC3.14 (CP2), IC5.2 (PC13/TAMPER-RTC), R37.2
/SD_CS: IC3.1 (#CS), IC5.33 (PB12/SPI2_NSS/I2S2_WS/I2C2_SMBAI/USART3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)
/SD_MISO: IC3.7 (DO), IC5.35 (PB14/SPI2_MISO/USART3_RTS/TIM1_CH2N), R24.1
/SD_MOSI: IC3.2 (DI), IC5.36 (PB15/SPI2_MOSI/I2S2_SD/TIM1_CH3N)
/SD_POW: C23.1, IC3.4 (VDD), L1.2
/SD_SCK: IC3.5 (SCLK), IC5.34 (PB13/SPI2_SCK/I2S2_CK/USART3_CTS/TIM1_C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)
/SD_WP: IC3.12 (WP2), IC5.30 (PB11/I2C2_SDA/USART3_RX/TIM2_CH4), R38.2
/SET_BTN: IC5.9 (PC1/ADC123_IN11), R59.1
/TCK: IC5.49 (JTCK/SWCLK/PA14), P3.4
/TDI: IC5.50 (JTDI/PA15/SPI3_NSS/I2S3_WS/TIM2_CH1_ETR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), P3.8
/TMS: IC5.46 (JTMS/SWDIO/PA13), P3.2
/USBDM: IC5.44 (PA11/USART1_CTS/CANRX/USBDM/TIM1_CH4), R20.2
/USBDP: IC5.45 (PA12/USART1_RTS/CANTX/USBDP/TIM1_ETR), R16.2, R21.2
/USB_P: IC5.40 (PC9/TIM8_CH4/SDIO_D1/TIM3_CH4), R19.1, R22.2
/VBAT_SENSE: IC5.15 (PA1/USART2_RTS/ADC123_IN1/TIM2_CH2/TIM2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), R27.2, R28.1
/VDNB: C61.2, R61.1, R64.1, SW2.2, SW2.4
/VOL_DN: IC5.38 (PC7/I2S3_MCK/TIM8_CH2/SDIO_D7/TIM3_CH2), IC5.60 (BOOT0), R61.2
/VOL_UP: IC5.37 (PC6/I2S2_MCK/TIM8_CH1/SDIO_D6/TIM3_CH1), R60.1
/VS1053_CS: IC1.23 (XCS), IC5.20 (PA4/SPI1_NSS/USART2_CK/DAC_OUT1/ADC12_I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)
/VS1053_DREQ: IC1.8 (DREQ), IC5.41 (PA8/USART1_CK/TIM1_CH1/MCO)
/VS1053_MISO: IC1.30 (SO), IC5.22 (PA6/SPI1_MISO/TIM8_BKIN/ADC12_IN6/TIM3_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)
/VS1053_MOSI: IC1.29 (SI), IC5.23 (PA7/SPI1_MOSI/TIM8_CH1N/ADC12_IN7/TIM3_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)
/VS1053_RST: IC1.3 (XRESET), IC5.17 (PA3/USART2_RX/TIM5_CH4/ADC123_IN3/TIM2_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), R1.1
/VS1053_SCK: IC1.28 (SCLK), IC5.21 (PA5/SPI1_SCK/DAC_OUT2/ADC12_IN5)
/VUPB: C60.2, R60.2, R63.2, SW1.2, SW1.4
GND: C1.2, C2.2, C11.1, C12.1, C13.1, C14.1, C15.1, C16.1, C17.1, C19.2, C22.2, C23.2, C24.1, C25.1, C26.2, C27.2, C28.1, C29.1, C30.2, C31.1, C32.2, C33.2, C34.2, C35.2, C36.2, C38.1, C41.2, C42.2, C43.2, C44.2, C47.2, C48.2, C49.1, C50.1, C51.1, C52.1, C53.1, C54.1, C55.2, C62.2, C63.2, D1.3 (GND), IC1.4 (DGND0), IC1.16 (DGND1), IC1.20 (DGND2), IC1.21 (DGND3), IC1.22 (DGND4), IC1.35 (GND), IC2.2 (Vss), IC3.3 (VSS), IC3.6 (VSS), IC3.10 (MNT), IC3.11 (WP1), IC3.13 (CP1), IC4.2 (GND), IC5.12 (VSSA), IC5.18 (VSS4), IC5.31 (VSS1), IC5.47 (VSS2), IC5.63 (VSS3), IC6.2 (GND), IC7.2 (GND), IC8.2 (GND), IC9.3 (VSS), P1.1, P2.5, P3.3, P3.5, P3.9, P6.1, P6.2, P6.14, P7.1, P7.2, Q1.2 (S), Q3.2 (S), Q4.2 (S), Q5.2 (S), R1.2, R4.2, R5.2, R6.2, R7.2, R8.2, R9.2, R15.2, R22.1, R28.2, R33.2, R39.2, R40.2, R43.2, R46.1, R47.2, R49.1, R50.2, R51.2, R52.2, R55.2, R57.1, R62.2, R63.1, R64.2, R66.2, SW3.1, SW3.3, SW11.3, SW11.4 (MECH), X1.2 (GND), X1.4 (GND), X3.2 (GND), X3.4 (GND)
GNDA: C5.1, C6.1, C7.2, C8.1, C9.1, C10.1, C18.2, C20.2, C21.2, IC1.37 (AGND0), IC1.40 (AGND1), IC1.41 (AGND2), IC1.47 (AGND3), P4.1, P9.1, R39.1
unnamed: IC3.9 (RSV), R25.1
unnamed: IC3.8 (RSV), R23.1
unnamed: C25.2, IC5.3 (PC14/OSC32_IN), X2.1
unnamed: C24.2, IC5.4 (PC15/OSC32_OUT), X2.2
unnamed: IC5.27 (PB1/ADC12_IN9/TIM3_CH4/TIM8_CH3N/TIM1_C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), R2.1
unnamed: IC5.28 (PB2/BOOT1), R46.2
unnamed: Q1.1 (G), R3.1, R13.2
unnamed: C46.2, R56.1, R57.2, SW10.4
unnamed: IC1.11 (GPIO6/I2S_SCLK), R40.1
unnamed: IC1.10 (GPIO3/SDATA), R7.1
unnamed: IC1.9 (GPIO2/DCLK), R6.1
unnamed: C5.2, IC1.1 (MICP/LINE1), R17.1
unnamed: C1.1, IC1.17 (XTALO), R12.1, X1.1
unnamed: IC1.34 (GPIO1), R5.1
unnamed: IC1.36 (GPIO4/I2S_LROUT), R8.1
unnamed: IC1.26 (RX), R26.2
unnamed: IC1.25 (GPIO5/I2S_MCLK), R9.1
unnamed: C7.1, IC1.44 (RCAP)
unnamed: IC1.33 (GPIO0), R4.1
unnamed: IC1.12 (GPIO7/I2S_SDATA), R43.1
unnamed: Q6.3 (D), R27.1
unnamed: Q5.3 (D), Q6.1 (G), R58.2
unnamed: Q4.3 (D), R36.2
unnamed: P2.3, R21.1
unnamed: P2.2, R20.1
unnamed: C28.2, IC5.6 (OSC_OUT/CAN_TX), R42.2, X3.3
unnamed: IC6.3 (EN), IC9.1 (RST)
unnamed: Q1.3 (D), Q2.1 (G), R14.2, R15.1
unnamed: Q2.2 (S), R16.1
unnamed: IC5.56 (JNTRST/PB4/SPI3_MISO/TIM3_CH1/SPI1_MISO), R67.2
unnamed: C2.1, IC1.18 (XTALI), R12.2, X1.3
unnamed: C29.2, IC5.5 (OSC_IN/CAN_RX), R42.1, X3.1
unnamed: C45.2, R32.2, R49.2, SW4.2, SW4.4
unnamed: C59.2, R59.2, R62.1, SW5.2, SW5.4
unnamed: C58.2, R48.2, R52.1, SW9.2, SW9.4
unnamed: C56.2, R34.2, R50.1, SW7.2, SW7.4
unnamed: C57.2, R44.2, R51.1, SW8.2, SW8.4
unnamed: IC2.5 (PROG), R35.1, R36.1
unnamed: D1.2 (GRN), R2.2
unnamed: C4.1, R18.2
unnamed: C36.1, P6.7
unnamed: C21.1, R31.2
unnamed: C6.2, IC1.48 (LINE2), R18.1
unnamed: IC1.46 (LEFT), P10.4a, P10.4b, R31.1
unnamed: C40.1, P6.12
unnamed: C39.1, P6.10
unnamed: C37.2, P6.9
unnamed: C32.1, P6.3
unnamed: C34.1, P6.5
unnamed: C39.2, C40.2, P6.11
unnamed: C41.1, P6.13
unnamed: C4.2, P9.3
unnamed: C20.1, R30.2
unnamed: C3.1, R17.2
unnamed: D1.1 (RED), R11.2
unnamed: C35.1, P6.6
unnamed: C33.1, P6.4
unnamed: C37.1, P6.8
unnamed: C3.2, P9.4b
unnamed: IC1.42 (GBUF), P10.1, R29.1, R45.1
unnamed: IC1.39 (RIGHT), P10.3, R30.1
unnamed: IC1.13 (XDCS/BSYNC), R10.2
unnamed: IC5.26 (PB0/ADC12_IN8/TIM3_CH3/TIM8_CH2N/TIM1_C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), R11.1
unnamed: C18.1, R29.2, R45.2

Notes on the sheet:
CODEC Chip
SD Card
USB Connector
Battery management
Power Supply
Screen
Buttons
Processor

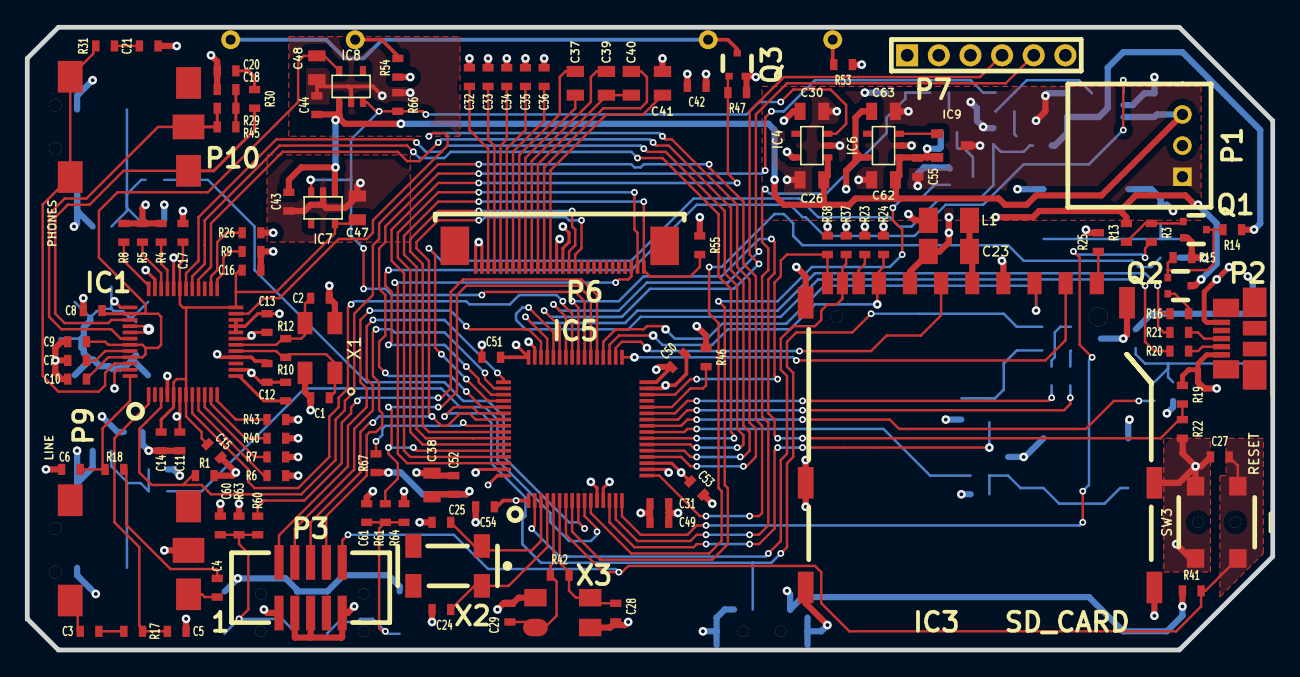
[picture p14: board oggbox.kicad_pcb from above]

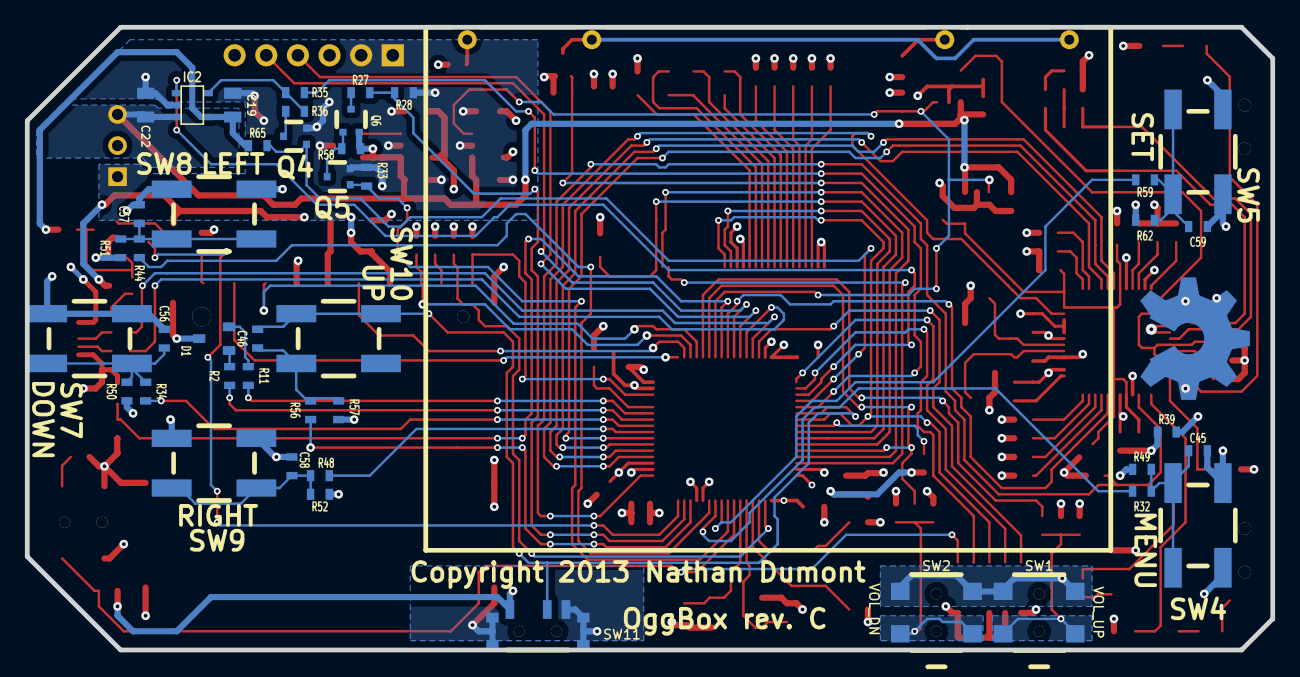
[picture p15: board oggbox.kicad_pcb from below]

Board: 4 copper layers, 100.0 x 50.0 mm, 169 parts (46 on the bottom side), 121 nets.

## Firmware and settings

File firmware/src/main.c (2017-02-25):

#include <stdint.h>
#include <stdlib.h>
#include <stdio.h>

#include <libopencm3/stm32/rcc.h>
#include <libopencm3/stm32/gpio.h>
#include <libopencm3/stm32/rtc.h>
#include <libopencm3/cm3/systick.h>
#include <libopencm3/cm3/scb.h>

#include "FreeRTOS.h"
#include "queue.h"
#include "task.h"

#include "block.h"
#include "fat.h"
#include "vs1053.h"
#include "partition.h"
#include "power.h"
#include "interface.h"
#include "config.h"
#include "nd_usart.h"

#define mainFLASH_DELAY 1000
#define LED_TASK_PRIORITY ( tskIDLE_PRIORITY + 1 )
#define LED_TASK_STACK_SIZE 128

xQueueHandle player_queue;

void hardware_setup() {
  
//   rcc_clock_setup_in_hse_8mhz_out_72mhz();
  rcc_clock_setup_in_hsi_out_48mhz();
  rcc_peripheral_enable_clock(&RCC_APB2ENR, RCC_APB2ENR_IOPAEN);
  rcc_peripheral_enable_clock(&RCC_APB2ENR, RCC_APB2ENR_IOPBEN);
  rcc_peripheral_enable_clock(&RCC_APB2ENR, RCC_APB2ENR_IOPCEN);
  rcc_peripheral_enable_clock(&RCC_APB2ENR, RCC_APB2ENR_IOPDEN);
  rcc_peripheral_enable_clock(&RCC_APB2ENR, RCC_APB2ENR_AFIOEN);
  rcc_peripheral_enable_clock(&RCC_APB1ENR, RCC_APB1ENR_PWREN);

  /* set the AUX_POWER line to on all the time, turning this off causes an error
     condition on the SPI bus to the CODEC.  In RevB this line is used for sensing
     the battery voltage and should be initialised as off */
//   gpio_set(GPIOB, GPIO5);
//   gpio_set_mode(GPIOB, GPIO_MODE_OUTPUT_2_MHZ,
//                 GPIO_CNF_OUTPUT_PUSHPULL, GPIO5);
  gpio_set_mode(AUX_POWER_PORT, GPIO_MODE_OUTPUT_50_MHZ,
                GPIO_CNF_OUTPUT_PUSHPULL, AUX_POWER_PIN);
                
  gpio_set_mode(GREEN_LED_PORT, GPIO_MODE_OUTPUT_2_MHZ,
                GPIO_CNF_OUTPUT_PUSHPULL, RED_LED_PIN | GREEN_LED_PIN);

  /* Turn off the JTAG port until next reset */
  AFIO_MAPR = AFIO_MAPR_SWJ_CFG_JTAG_OFF_SW_OFF;
}

void queue_setup() {
  player_queue = xQueueCreate(10, sizeof(struct player_job));
}

static void FlashLEDTask( void *pvParameters __attribute__((__unused__))) {
    while(1) {
        /* Simple toggle the LED periodically.  This just provides some timing
            verification. */
        vTaskDelay(1000);
        gpio_toggle(RED_LED_PORT, RED_LED_PIN);
        iprintf("LED task\r\n");
    }
    configASSERT(0);
}

int main(void) {
  int r, i, mounted=0;
  uint8_t buffer[512];
  struct partition *part_list;
  
  scb_set_priority_grouping(SCB_AIRCR_PRIGROUP_GROUP16_NOSUB);
  
  hardware_setup();
  /* configure the UART for printf debug console */
  usart_clock_setup();
  usart_setup();
        
  power_aux_on();

  // setup the systick counter for timeouts etc.
//   systick_set_clocksource(STK_CTRL_CLKSOURCE_AHB_DIV8);
  // 9000000 counts per second @ 72MHz
//   systick_set_reload(9000);
  // reload every millisecond
  
  iprintf("==================================================\r\n");
  r = block_init();
  iprintf("Block init: %d\r\n", r);
  if(r == 0) {
    r = fat_mount(0, block_get_volume_size(), 0);
    iprintf("Mount card root: %d\r\n", r);
    if(r != 0) {
      block_read(0, buffer);
      r = read_partition_table(buffer, block_get_volume_size(), &part_list);
      iprintf("Found %d partitions\r\n", r);
      if(r > 0) {
        for(i=0;i<r;i++) {
          if(fat_mount(part_list[i].start, part_list[i].length, part_list[i].type) == 0) {
            iprintf("Mounted partition %d\r\n", i);
            mounted = 1;
            break;
          }
        }
      }
    } else {
      mounted = 1;
    }
  }
  
  queue_setup();
  
  configASSERT(xTaskCreate(FlashLEDTask, "LED", LED_TASK_STACK_SIZE, NULL, LED_TASK_PRIORITY, NULL) == pdPASS);
  
  start_player_task();
  
  start_power_management_task();
  
  start_interface_task();
  
  vTaskStartScheduler();
  
  configASSERT(0);
  iprintf("Start scheduler failed!\r\n");

  // the previous call should never return
  return 0;
}

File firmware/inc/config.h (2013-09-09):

/*
 * config.h
 *
 * Contains all the hardware specific configuration and pin definitions
 */
#ifndef OGGBOX_H
#define OGGBOX_H 1

// SD card interface
#define SD_SPI        SPI2
#define SD_PORT       GPIOB
#define SD_CS_PIN     GPIO12
#define SD_MOSI_PIN   GPIO15
#define SD_MISO_PIN   GPIO14
#define SD_SCK_PIN    GPIO13
#define SD_WP_PIN     GPIO11
#define SD_WP_PORT    GPIOB
#define SD_CP_PIN     GPIO13
#define SD_CP_PORT    GPIOC

#define SD_SPI_APB    RCC_APB1ENR
#define SD_RCC_SPI    RCC_APB1ENR_SPI2EN
#define SD_IO_APB     RCC_APB2ENR
#define SD_RCC_IO     RCC_APB2ENR_IOPBEN

// LED indicator
#define GREEN_LED_PORT GPIOB
#define GREEN_LED_PIN GPIO1
#define RED_LED_PORT GPIOB
#define RED_LED_PIN GPIO0

// LCD pins
#define LCD_CS_PORT   GPIOB
#define LCD_CS_PIN    GPIO7
#define LCD_RST_PORT  GPIOB
#define LCD_RST_PIN   GPIO6
#define LCD_BL_PORT   GPIOB
#define LCD_BL_PIN    GPIO8
#define LCD_DC_PORT   GPIOB
#define LCD_DC_PIN    GPIO9
#define LCD_MOSI_PORT GPIOB
#define LCD_MOSI_PIN  GPIO5
#define LCD_SCK_PORT  GPIOB
#define LCD_SCK_PIN   GPIO3

#define LCD_SPI       SPI3

// codec hardware
#define CODEC_PORT      GPIOA
#define CODEC_CS        GPIO4
#define CODEC_SCK       GPIO5
#define CODEC_MISO      GPIO6
#define CODEC_MOSI      GPIO7

#define CODEC_DREQ_PORT GPIOA
#define CODEC_DREQ      GPIO8
#define CODEC_RST_PORT  GPIOA
#define CODEC_RST       GPIO3
#define CODEC_PWR_PORT  GPIOB
#define CODEC_PWR       GPIO5

#define CODEC_IOS_APB   RCC_APB2ENR
#define CODEC_RCC_IOS   RCC_APB2ENR_IOPAEN

#define CODEC_PWR_APB   RCC_APB2ENR
#define CODEC_RCC_PWR   RCC_APB2ENR_IOPBEN

#define CODEC_IOI_APB   RCC_APB2ENR
#define CODEC_RCC_IOI   RCC_APB2ENR_IOPCEN

#define CODEC_SPI       SPI1
#define CODEC_SPI_APB   RCC_APB2ENR
#define CODEC_RCC_SPI   RCC_APB2ENR_SPI1EN

// Power management
#define AUX_POWER_PORT GPIOC
#define AUX_POWER_PIN GPIO8

#define BAT_CHK_PORT  GPIOC
#define BAT_CHK_PIN   GPIO0

#define BAT_VAL_PORT  GPIOA
#define BAT_VAL_PIN   GPIO1

#define USB_P_PORT    GPIOC
#define USB_P_PIN     GPIO9

#define CHG_STAT_PORT GPIOC
#define CHG_STAT_PIN  GPIO10

#define CHG_100_PORT  GPIOC
#define CHG_100_PIN   GPIO11

#define CHG_500_PORT  GPIOC
#define CHG_500_PIN   GPIO12

// Button definitions
#define VOL_UP_PORT     GPIOC
#define VOL_UP_PIN      GPIO6

#define VOL_DOWN_PORT   GPIOC
#define VOL_DOWN_PIN    GPIO7

#define MENU_BTN_PORT   GPIOC
#define MENU_BTN_PIN    GPIO2

#define SET_BTN_PORT    GPIOC
#define SET_BTN_PIN     GPIO1

#define UP_BTN_PORT     GPIOA
#define UP_BTN_PIN      GPIO0

#define LEFT_BTN_PORT   GPIOC
#define LEFT_BTN_PIN    GPIO3

#define RIGHT_BTN_PORT  GPIOC
#define RIGHT_BTN_PIN   GPIO4

#define DOWN_BTN_PORT   GPIOC
#define DOWN_BTN_PIN    GPIO5

// USB stuff
#define USB_DISC_PORT   GPIOA
#define USB_DISC_PIN    GPIO2

// stdio definitions
#define STD_OUT_UART  USART1
#define STD_ERR_UART  USART1
#define STD_IN_UART   USART1

#endif /* ifndef OGGBOX_H */

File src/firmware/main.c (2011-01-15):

/*
 * This file is part of the oggbox project.
 *
 * Copyright (C) 2010 Nathan Dumont (hairymnstr@gmail.com)
 *
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
 * You should have received a copy of the GNU General Public License
 * along with this program.  If not, see <http://www.gnu.org/licenses/>.
 */

#include <libopenstm32/rcc.h>
#include <libopenstm32/gpio.h>
#include <libopenstm32/usart.h>
#include <libopenstm32/spi.h>     // debug, remove later

#include "ob_stdio.h"
#include "ob_screen.h"
#include "config.h"

extern void _etext, _data, _edata, _bss, _ebss, _stack;

void clock_setup(void)
{
	rcc_clock_setup_in_hse_8mhz_out_72mhz();

	/* Enable GPIOC clock. */
  rcc_peripheral_enable_clock(&RCC_APB2ENR, RCC_APB2ENR_IOPAEN);
  rcc_peripheral_enable_clock(&RCC_APB2ENR, RCC_APB2ENR_IOPBEN);
	rcc_peripheral_enable_clock(&RCC_APB2ENR, RCC_APB2ENR_IOPCEN);
  rcc_peripheral_enable_clock(&RCC_APB2ENR, RCC_APB2ENR_IOPDEN);
}

void gpio_setup(void)
{
	/* Set GPIO12 (in GPIO port C) to 'output push-pull'. */
	gpio_set_mode(GPIOC, GPIO_MODE_OUTPUT_2_MHZ,
		      GPIO_CNF_OUTPUT_PUSHPULL, GPIO12);
//  gpio_set_mode(GPIOC, GPIO_MODE_OUTPUT_50_MHZ,
//          GPIO_CNF_OUTPUT_PUSHPULL, 0xFF);
//  gpio_set_mode(GPIOC, GPIO_MODE_OUTPUT_50_MHZ,
//          GPIO_CNF_OUTPUT_PUSHPULL, GPIO8 | GPIO9 | GPIO10 | GPIO13);
//  gpio_set_mode(GPIOA, GPIO_MODE_OUTPUT_50_MHZ,
//          GPIO_CNF_OUTPUT_PUSHPULL, GPIO1);
//  gpio_set_mode(GPIOD, GPIO_MODE_OUTPUT_50_MHZ,
//          GPIO_CNF_OUTPUT_PUSHPULL, GPIO2);
}

void usart_setup(void) {
  rcc_peripheral_enable_clock(&RCC_DBGURTIO, RCC_DBGURTIO_EN);
  rcc_peripheral_enable_clock(&RCC_DBGURT, RCC_DBGURT_EN);

  gpio_set_mode(DBG_URT_TX_BANK, GPIO_MODE_OUTPUT_50_MHZ,
                GPIO_CNF_OUTPUT_ALTFN_PUSHPULL, DBG_URT_TX);

  usart_set_baudrate(DBG_URT, 38400);
  usart_set_databits(DBG_URT, 8);
  usart_set_stopbits(DBG_URT, USART_STOPBITS_1);
  usart_set_mode(DBG_URT, USART_MODE_TX);
  usart_set_parity(DBG_URT, USART_PARITY_NONE);
  usart_set_flow_control(DBG_URT, USART_FLOWCONTROL_NONE);

  usart_enable(DBG_URT);
}

int main(void) {
	int i, j;
  __builtin_memcpy(&_data, &_etext, &_edata - &_data);
  __builtin_memset(&_bss, 0, &_ebss - &_bss);

	clock_setup();
	gpio_setup();
	usart_setup();
  ob_screen_setup();

  ob_screen_set_bl(65535);

  ob_printf("Hello world the answer is %d\n", 42);

  unsigned short l = 0;
  ob_screen_set_bl(16384);

  ob_screen_set_contrast(32768);

  ob_screen_startup();

  ob_printf("running screen test\n");

//  ob_screen_test();

  ob_screen_print("Hello World");

  while(1) {;}
/*  gpio_set(SCREEN_RST_PORT, SCREEN_RST);

  gpio_clear(GPIOC, GPIO8);
  gpio_set(GPIOC, GPIO9);

  gpio_set(GPIOC, GPIO13);

  gpio_clear(GPIOA, GPIO1);
  gpio_set(GPIOD, GPIO2);

//  SCREEN_DATA_OUT = (SCREEN_DATA_OUT & 0xFF00) | 0xAA;

//  ob_printf("%x, %x\n", GPIOC_CRL, GPIOC_CRH);
  //ob_printf("%x\n", 0x44444444);

//  ob_printf("Screen running\n");

  for(j=0;j<50;j++) {
    //ob_screen_set_bl(l);
    //l += 128;
  //  ob_printf("%d\n", l);
  //  SCREEN_DATA_OUT = (SCREEN_DATA_OUT & 0xFF00) | 0xAA;
    for(i=0;i<1000000;i++);
    ob_printf("%x\n", SCREEN_DATA_IN);
  //  SCREEN_DATA_OUT = (SCREEN_DATA_OUT & 0xFF00) | 0x55;
  //  for(i=0;i<1000000;i++);
  }

  gpio_clear(GPIOD, GPIO2);
  gpio_clear(GPIOC, GPIO13);
  gpio_set_mode(GPIOC, GPIO_MODE_OUTPUT_50_MHZ,
          GPIO_CNF_OUTPUT_PUSHPULL, 0xFF);

  ob_printf("%x, %x\n", GPIOC_CRL, GPIOC_CRH);

  SCREEN_DATA_OUT = (SCREEN_DATA_OUT & 0xFF00) | 0x3F;
  for(j=0;j<50;j++) {
    //ob_screen_set_bl(l);
    //l += 128;
  //  ob_printf("%d\n", l);
  //  SCREEN_DATA_OUT = (SCREEN_DATA_OUT & 0xFF00) | 0xAA;
    for(i=0;i<1000000;i++);
    ob_printf("%x\n", SCREEN_DATA_IN);
  //  SCREEN_DATA_OUT = (SCREEN_DATA_OUT & 0xFF00) | 0x55;
  //  for(i=0;i<1000000;i++);
  }

  gpio_set(GPIOD, GPIO2);
  for(i=0;i<1000000;i++);
  gpio_clear(GPIOD, GPIO2);

  gpio_set_mode(GPIOC, GPIO_MODE_INPUT,
          GPIO_CNF_INPUT_FLOAT, 0xFF);

  for(i=0;i<1000000;i++);

  ob_printf("%x, %x\n", GPIOC_CRL, GPIOC_CRH);

  gpio_set(GPIOC, GPIO13);

  for(i=0;i<1000000;i++);

  gpio_set(GPIOD, GPIO2);

  for(j=0;j<50;j++) {
    //ob_screen_set_bl(l);
    //l += 128;
  //  ob_printf("%d\n", l);
  //  SCREEN_DATA_OUT = (SCREEN_DATA_OUT & 0xFF00) | 0xAA;
    for(i=0;i<1000000;i++);
    ob_printf("%x\n", SCREEN_DATA_IN);
  //  SCREEN_DATA_OUT = (SCREEN_DATA_OUT & 0xFF00) | 0x55;
  //  for(i=0;i<1000000;i++);
  }
 
  gpio_clear(GPIOD, GPIO2);

  for(i=0;i<1000000;i++);

  gpio_set(GPIOD, GPIO2);

  for(j=0;j<50;j++) {
    //ob_screen_set_bl(l);
    //l += 128;
  //  ob_printf("%d\n", l);
  //  SCREEN_DATA_OUT = (SCREEN_DATA_OUT & 0xFF00) | 0xAA;
    for(i=0;i<1000000;i++);
    ob_printf("%x\n", SCREEN_DATA_IN);
  //  SCREEN_DATA_OUT = (SCREEN_DATA_OUT & 0xFF00) | 0x55;
  //  for(i=0;i<1000000;i++);
  }
 */

	return 0;
}

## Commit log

2010-11-28 Initial commit, working "hello_world" over uart for oggbox
2010-12-08 Fixed a bug in itoa and started screen printing, doesn't work though.
    [config.h, main.c]
2010-12-14 Screen works, hardware bug with contrast now. itoa bugs fixed again
    [main.c]
2011-01-12 Added high level set/get for row/col/inv and print functions to screen.
2011-01-15 Created a font based on IBM code page 437. Print to screen now works.
2012-02-19 Added schematic to git, about to annotate and start PCB
    [oggbox.sch]
2012-05-17 Forgot to keep git up to date, loads of updates.
    [oggbox.brd, oggbox.sch, screen_breakout.brd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]
2012-05-17 More PCB routing, removed some unneccessary stuff and tidied up the charger circuit. Bi colour LED now on the STM32 not VS1053
    [oggbox.brd, oggbox.sch]
2012-05-17 Corrected a USB pinout bug in schematic and netlist. Re-arranging power/USB wiring.
    [oggbox.brd, oggbox.sch]
2012-05-17 More routing on the PCB. Making some progress slowly.
    [oggbox.brd]
2012-05-17 More routing.
    [oggbox.brd]
2012-05-21 More routing. Some schematic fixes, now 3.0V not 3.3V
    [oggbox.brd, oggbox.sch]
2012-05-22 100% routed!
    [oggbox.brd, oggbox.sch]
2012-05-22 Clean up tracks/vias
    [oggbox.brd]
2012-05-22 More fiddling with tracks
    [oggbox.brd]
2012-05-23 Added some silk screen stuff
    [oggbox.brd]
2012-05-23 Tidied up all the silk screen should be ready for manufacture.
    [oggbox.brd, oggbox.sch]
2012-05-23 Fixed volume button labels.
    [oggbox.brd]
2012-05-23 Changed the drill hole to PTH on side switches
    [oggbox.brd]
2012-05-23 Version that was sent to iTead for manufacture.
    [oggbox.brd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]
2012-06-02 Back annotated footprints for faster BOM generation
    [oggbox.csv, oggbox.sch]
2012-06-09 Sorting out code directory ready for Rev A firmware
    [oggbox.csv, oggbox.ods]
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2012-06-27 Trying to get the stdio stuff working. Failing so far.
    [config.h, lcd.c]
2012-07-10 Working on some sort of power problem
2012-07-11 Got it working, hardware mistake. Still high current problems
2012-07-13 Committed RevA to PDF and started moding schematic for RevB
    [oggbox.sch]
2012-07-26 Working on RevB schematic a bit more. PSU redesign.
    [oggbox.sch]
2012-08-03 Asynchronous player now working correctly.
    [vs1053.c]
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2012-08-17 Working for OggCamp, can't play less than 192kbps because of blocking interrupts not reading disk sectors
2012-09-05 Working on the SD card blocking problem, doesn't work at the moment.
    [vs1053.c]
2012-09-11 Still working on SD card blocking problems
    [vs1053.c]
2012-09-11 Now working. codec IRQ needs priority 16+ to avoid interrupting SD DMA
    [vs1053.c]
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2012-09-20 Preparing to lay out Rev B board
    [oggbox.sch]
2012-09-22 Re-routed the power supply control for RevB
    [oggbox.brd, oggbox.sch]
2012-09-22 Placed new resistors for RevB
    [oggbox.brd]
2012-09-23 Changed the side switches to new footprint, not routed.
    [oggbox.brd]
2012-09-23 Routed the new volume switches
    [oggbox.brd, oggbox.sch]
2012-09-23 Changed the footprint of the RTC crystal to an SMD part
    [oggbox.brd, oggbox.sch]
2012-09-23 Re-routed all the power supply around the newly placed serial header
    [oggbox.brd]
2012-09-24 Moving stuff around to try and shift the SD socket
    [oggbox.brd, oggbox.sch]
2012-09-24 Re-routed all the power to fit new reset switch, SD socket still needs moving
    [oggbox.brd]
2012-09-24 Moved the SD card socket back 3mm
    [oggbox.brd]
2012-09-24 Moved another 0.5mm to make sure the LED is clear of the mounting holes on the SD socket
    [oggbox.brd]
2012-09-24 Added option to use goodluckbuy SD sockets
    [oggbox.brd]
2012-09-24 Added extra decoupling and updated silkscreen
    [oggbox.brd, oggbox.sch]
2012-09-25 Tidied up the silkscreen layout for manufacture
    [oggbox.brd]
2012-09-25 Tinkering with ground plane and 3D models
    [oggbox.brd]
2012-09-26 Final tweaks ready to make gerbers and order a RevB board
    [oggbox.brd]
2012-09-26 Moved rev A gerbers to a separate file, might be handy to keep them in trunk
    [oggbox.GBL, oggbox.GBO, oggbox.GBS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]
2012-09-26 Final edits of Rev B, now submitted for manufacture
    [oggbox.brd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]
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2012-12-20 Found a bug in mount, sectors_per_fat was not properly initialised.
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2013-02-22 Started the Rev C schematic, just changed the battery voltage check switch to a P type MOSFET
    [oggbox.sch]
2013-02-25 Started laying out the Rev C board
    [oggbox.sch]
2013-02-26 Made some more schematic revisions for the Rev C
    [oggbox.sch]
2013-07-24 Oggbox Rev C almost ready to order!
    [oggbox.brd, oggbox.sch]
2013-08-03 Ready to order the Rev C PCBs.
    [oggbox.brd, oggbox.sch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]
2013-08-05 Final changes for the Rev C board order.
    [oggbox.brd]
2013-08-17 Started working on the firmware for Rev C. Introducing the new FAT routines with abstracted block layer. Rewritten the linker script for the STM32F103RET6
    [oggbox.brd]
2013-08-27 Moving source tree around about to start working on RTOS stuff. Currently does play a file
    [oggbox-B_Cu.gbl, oggbox-B_Mask.gbs, oggbox-B_SilkS.gbo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]
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2013-08-31 Added the basic screen driver and got USB charging working with basic USB serial emulation
2013-09-01 Lots of work on screen driver and UI, displays artist, track and album and scrolls if they don't fit on screen. Ogg meta information imported from the old source.
2013-09-12 Fixed a couple of edge case for FAT16 handling in the FAT library
2013-09-13 Started work on a case design, so far just roughing-out the PCBA as a 3D model
    [oggbox.scad]
2013-09-19 More cad stuff and a functional UTF-8 to Ascii converter for removing accents from meta tags.
    [oggbox.scad, oggbox.stl]
2013-10-05 Massive heap of new code to do with database creation
    [oggbox.scad, oggbox_back.stl, oggbox_buttons.stl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]
2013-10-06 Now shuts down to ~600uA standby mode if you hold up button, then wakes up if you press up again
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2019-10-03 Migrated the oggbox to KiCad 5.x with all local libraries
    [oggbox-B_Cu.gbl, oggbox-B_Mask.gbs, oggbox-B_SilkS.gbo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]
2019-10-11 Updated the OggBox project to work with KiCad v5, made it a demo for automated manufacturing outputs
    [oggbox.csv, oggbox.kicad_pcb, oggbox.sch]

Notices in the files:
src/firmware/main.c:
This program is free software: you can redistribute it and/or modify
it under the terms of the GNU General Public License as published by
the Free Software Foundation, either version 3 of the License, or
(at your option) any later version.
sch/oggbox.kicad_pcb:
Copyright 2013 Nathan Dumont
